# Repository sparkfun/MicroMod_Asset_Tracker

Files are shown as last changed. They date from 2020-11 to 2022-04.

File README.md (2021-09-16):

# MicroMod Asset Tracker Carrier Board

SparkFun MicroMod Asset Tracker Carrier Board (https://www.sparkfun.com/products/17272)

[*SparkFun MicroMod Asset Tracker Carrier Board (DEV-17272)*](https://www.sparkfun.com/products/17272)

The MicroMod Asset Tracker Carrier Board provides you with a toolkit to monitor and track the location of your assets. Built around the u-blox SARA-R510M8S module, the asset tracker offers Secure Cloud LTE-M data communication for multi-regional use and has an integrated u-blox M8 GNSS receiver for accurate positioning information. The SARA-R5 supports many different forms of data communication from full TCP/IP sockets and packet switched data, through HTTP Get/Put/Post, FTP (the SARA has a built-in file system), Ping, to good old SMS text messaging!

The Asset Tracker Carrier Board has an integrated ICM-20948 Inertial Measurement Unit (IMU) for Nine Degree-Of-Freedom orientation and movement detection. Want to send a message if your asset is moved? The Asset Tracker can do that! The board also has a built-in digital microphone and so can send an alert as soon as a noise is detected too.

The SparkFun Asset Tracker Carrier Board also has a built-in micro-SD card socket for data logging. Power options include both USB-C and LiPo battery (with built-in charging and battery fuel gauge), but you can provide power via a breakout pin too.

## Repository Contents

* **/Examples** - A set of examples demonstrating how to use each component on the Asset Tracker. Run these from the Arduino IDE.
* **/Documentation** - Datasheets etc.
* **/Hardware** - Eagle PCB, SCH and LBR design files. Full schematic in PDF format.
* **[LICENSE.md](./LICENSE.md)** - License details

## Documentation

* **[SparkFun u-blox SARA-R5 Arduino Library](https://github.com/sparkfun/SparkFun_u-blox_SARA-R5_Arduino_Library)** - An Arduino library for the SARA-R5 Module
* **[Hookup Guide](https://learn.sparkfun.com/tutorials/micromod-asset-tracker-carrier-board-hookup-guide)** - Basic Hookup Guide for the MicroMod Asset Tracker Carrier Board
* **[Getting Started with MicroMod](https://learn.sparkfun.com/tutorials/getting-started-with-micromod)** -  A tutorial to help you get started with the MicroMod Ecosystem.
* **[Designing with MicroMod](https://learn.sparkfun.com/tutorials/designing-with-micromod)** - A tutorial to walk you through the specs of the MicroMod processor and carrier board as well as the basics of incorporating the MicroMod form factor into your own PCB designs.

## Product Versions

* [DEV-17272](https://www.sparkfun.com/products/17272) - The MicroMod Asset Tracker Carrier Board uses the u-blox SARA-R5 LTE-M / NB-IoT module to provide a powerful development tool.

## License Information

This product is _**open source**_!

Please review the LICENSE.md file for license information.

If you have any questions or concerns on licensing, please contact technical support on our [SparkFun forums](https://forum.sparkfun.com/viewforum.php?f=152).

Distributed as-is; no warranty is given.

- Your friends at SparkFun.

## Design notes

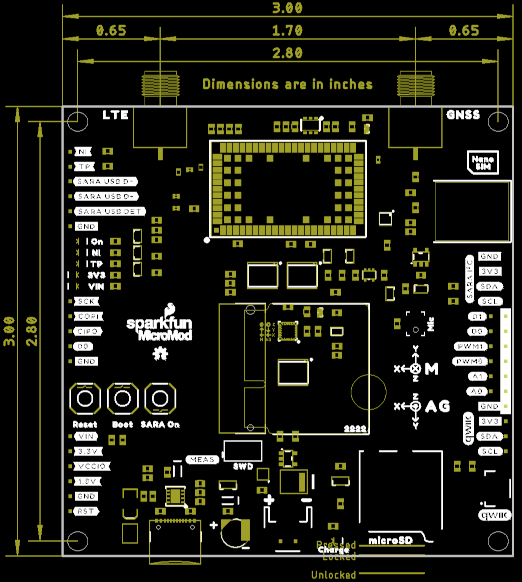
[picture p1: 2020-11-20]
img/Dimensions.png

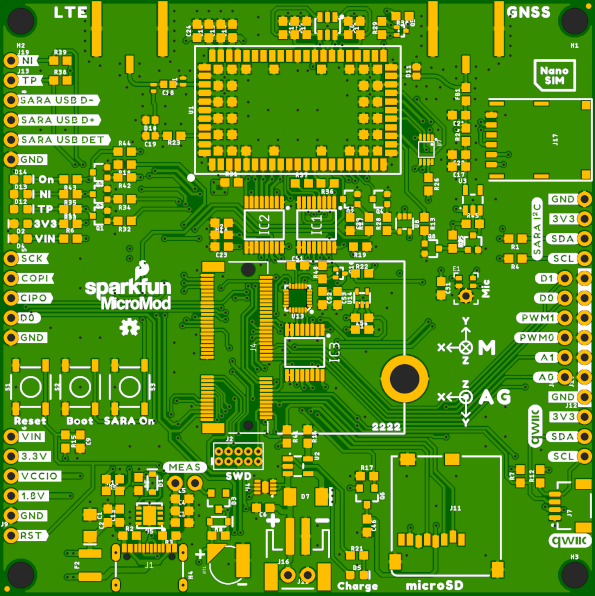
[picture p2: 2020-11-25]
img/Top.png

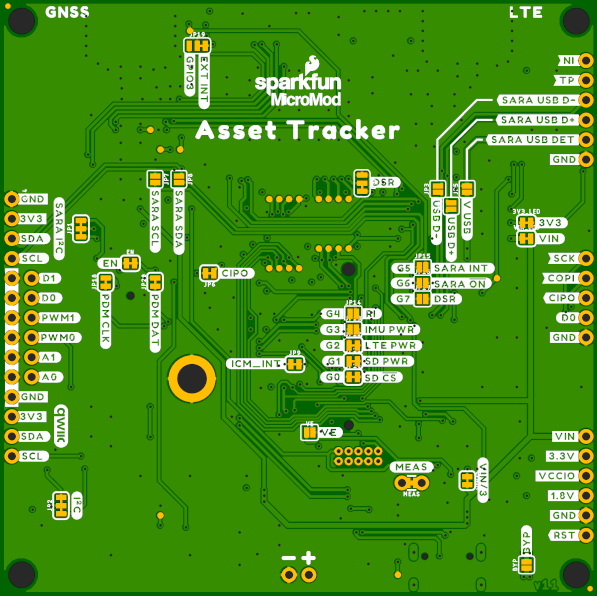
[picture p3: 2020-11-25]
img/Bottom.png

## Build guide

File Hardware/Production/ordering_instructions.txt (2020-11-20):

panel size, 167x194mm
PCB thickness, 1.6mm
number of layers, 4
soldermask color, Red
silkscreen color, White
oz copper, 1oz
finish, HASL lead free
stencils, top
pcs per panel, 4
min trace width, 0.2032mm / 0.0080in
min drill size, 0.3000mm / 0.0118in
filename to layer stackup 1/2/3/4: GTL, GL2, GL3, GBL

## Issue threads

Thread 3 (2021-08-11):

add support for STM32 Micromod

adpjhu, 2021-08-11:
i added the following to "AssetTrackerPins.h"

seems to have made it work w/ STM32 micromod

`#if defined(ARDUINO_ARCH_STM32)
#define G7 -1
#define BATTVIN3 BATT_VIN
#define I2CINT INT
HardwareSerial Serial1(RX1, TX1);
#endif`

PaulZC, 2021-08-12:
Thank you @adpjhu ,
We will test this and add it to the examples as soon as we can.
Best wishes,
Paul

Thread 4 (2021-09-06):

Charger compatibility with Lifepo4

cdumitras-plog, 2021-09-06:
Hello,
Considering the use of this device (car tracker), the use of litium ion batteries might be considered a risk.
In cars depending on conditions temperature can be high, increasing the risk of fire with lithium ion.

Is this charger compatible with lifepo4 ?
If not could you consider a future revision with such a change ?

I consider this device to be a very strong platform for asset tracking,
Thank you for your hard work!

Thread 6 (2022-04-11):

No example nor processor board that works

ajsb85, 2022-04-11:
Hi, I try all the processor boards and all the examples.

And no one works.

Seems the **nRF5280 Processor** is the perfect for this carrier board, but is broken the Arduino file when you install the board.

https://github.com/sparkfun/MicroMod_Processor_Board-nRF52840/issues/3

Cheers.

PaulZC, 2022-04-11:
Hi Alexander (@ajsb85 ),

They do work - trust me - I've been using them today.

For the nRF52840, there are some extra steps to create the SparkFun MicroMod nRF52840 Processor Board. Follow the instructions here:

https://learn.sparkfun.com/tutorials/micromod-nrf52840-processor-hookup-guide/arduino-software-setup

Then select the correct Board:

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

If you are still having problems, please upload a copy of any error messages you are seeing.

Best wishes,
Paul

ajsb85, 2022-04-21:
No.
And I read the forum posts and nothing works.
The board base from Arduino was updated and not the files provided by SparkFun.
If you can tell me which version of the Arduino boards works I can downgrade it...

PaulZC, 2022-04-21:
Hello Alexander,

I followed the instructions in the hook-up guide - but it was a few months ago. I am using "Arduino Mbed OS Boards" Version 1.3.1 DEPRECATED:

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

But I see that the repository has been updated so that it should work with the newer "Arduino Mbed OS Nano Boards" Version 3.0.1:

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

Please try "Arduino Mbed OS Nano Boards" Version 3.0.1 - using the link in the hook-up guide:

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

https://github.com/sparkfun/MicroMod_Processor_Board-nRF52840/archive/master.zip

If you still have problems, please try "Arduino Mbed OS Boards" Version 1.3.1 DEPRECATED - and use the link below to download an older version of the SF_MM_nRF52840_PB files. This is the same one I am using.

https://github.com/sparkfun/MicroMod_Processor_Board-nRF52840/archive/4bddb83c139195fad9654aa633374239504ced05.zip

If, after this, you are still having problems, please provide more information:

Do you see any errors in the Arduino IDE when compiling and uploading the code?

What do you see in the Serial Monitor when the code is running?

How do you have the board connected?

Which LEDs are lit up on the board?

Have you tried the simplest "AssetTracker_Example1_Blink"? Does the LED on the processor board blink?

Thank you,
Paul

ajsb85, 2022-04-26:
Dear @PaulZC .

I tried both versions of the DEPRECATED board 3.0.1 and 1.3.1 and I got the same error for both in the process of the uploading.

```
An error occurred while uploading the sketch
SAM-BA operation failed****
```

ajsb85, 2022-04-27:
It's working. (1.3.1)
I really appreciate it.

PaulZC, 2022-12-30:
Closing... Please re-open if you need more help with this.
Best,
Paul

Closed 2022-12-30.

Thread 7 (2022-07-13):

AWS IoT ExpressLink Asset Tracker |  Cannot initialize SARA with Examples on ESP32

alex-dsbz, 2022-07-13:
Hi.

I'm having issues with running any examples that include the initialisation of the SARA board. All of the other examples work with no issue.

Let's take Example12 - Identification.
When uploading it to the MicroMod ESP32, this is what I get from the serial monitor of Arduino

````
Asset Tracker Example

Initializing the SARA-R5...
...this may take ~25 seconds if the SARA is off.
...it may take ~5 seconds if it just turned on.

Press any key to continue...
init: Begin module init.
sendCommandWithResponse: Command: E0
init: Module failed echo test.
init: Begin module init.
init: Attempting autobaud connection to module.
sendCommandWithResponse: Command: +IPR=9600
sendCommandWithResponse: Command:
sendCommandWithResponse: Command: +IPR=9600
sendCommandWithResponse: Command:
sendCommandWithResponse: Command: +IPR=9600
sendCommandWithResponse: Command:
sendCommandWithResponse: Command: +IPR=9600
sendCommandWithResponse: Command:
sendCommandWithResponse: Command: +IPR=9600
sendCommandWithResponse: Command:
sendCommandWithResponse: Command: +IPR=9600
sendCommandWithResponse: Command:
init: Begin module init.
init: Power cycling module.
powerOff: complete
powerOn: complete

````
This sequence loops a couple time before its asking to manually turn on the SARA.

However the SARA IS turned on, and is being turned on and off by the initialisation script.

I've posted on the Sparkfun forum, but did not get any assistance so far.

I would love to be pointed in the right direction as I've exhausted all I could think off...

PaulZC, 2022-07-13:
Hi @alex-dsbz ,

From the title of the issue, I guess you are using the ESP32 MicroMod Processor Board?
Which version of the Espressif ESP32 board package do you have installed? (Probably v2.0.3 or 2.0.4?)
Which LEDs are illuminated?
Have you made any changes to the jumper links on the board?

Many thanks,
Paul

alex-dsbz, 2022-07-13:
Hi Paul,

Thanks for reaching back, I really appreciate it!

So I'm using the AWS IoT ExpressLink SARA-R5 Starter Kit  https://www.sparkfun.com/products/18450

All I have done is swap the Asset Tracker Update Tool MicroMod with the ESP32 and plug the carrier board by USB-C to my macbook.

I have uploaded the following example https://github.com/sparkfun/MicroMod_Asset_Tracker/tree/main/Examples/AssetTracker_Example12_Identification

In terms of Boards package, I have two installed:
- esp32 by Espressif Systems version 1.0.6 (that's the latest according to the Arduino IDE)
- Sparkfun Esp32 Boards version 1.0.1

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

In terms of LED:
- VIN is orange
- 3C3 is red
- On is white

I hope that answers your questions :)

Alex

PaulZC, 2022-07-13:
Hi Alex (@alex-dsbz ),

Many thanks for the detailed reply.

The SARA-R5 on the AWS IoT ExpressLink version of the Asset Tracker was programmed with special firmware. From the product page:

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

I must confess, I've never had one of those boards to test.

I designed the original version of the board and wrote the original Arduino Library and Examples. But I did all of that with boards running the standard SARA-R5 firmware - which responds to 'regular' AT commands.

I suspect the AWS version of the module is ignoring or not responding to the initial **E0** 'ping'. But, I've got no way to confirm that just now...

I'm really not sure how best to proceed.

I can ask my colleagues to send over one of the AWS boards so I can replicate your set-up. But, the end result _could_ be that it's just not possible to use the Arduino examples with that board...

Apologies,
Paul

alex-dsbz, 2022-07-13:
Oh I see, that does make sense!
At least now I know, there is nothing wrong with the board :)

Thanks a lot for your help!

PaulZC, 2022-07-23:
Hi Alex,

Just adding a link to the forum issue, just in case anyone else has the same issue:

https://forum.sparkfun.com/viewtopic.php?p=234780#p234780

Very best wishes,
Paul

Closed 2022-07-13.

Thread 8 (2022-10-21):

MicroMod Asset Tracker Carrier board with Samd51, Arduino IDE giving Missing FBQN error

jwalway, 2022-10-21:
Hello,

I have a **SparkFun MicroMod Asset Tracker Carrier** board that has a **Samd51 processor** board plugged into it.
I'm using the **Arduino IDE 2.0** in an attempt to code the board. I'm on _Windows 10_ and the board is plugged into my usb com port. Right now I'm just experimenting. I'm relatively new to this kind of programming. I downloaded libraries for both boards. When I attempt to compile a short sketch/script I get the following error: **Missing FBQN** (Fully Qualified Board Name). I can't get the Arduino IDE to recognize the Asset Tracker board, nor do I see it listed among their boards. I also don't see the samd51. I do see samd21.

I'm trying the first example here:
[https://learn.sparkfun.com/tutorials/mi ... o-examples](https://learn.sparkfun.com/tutorials/micromod-asset-tracker-carrier-board-hookup-guide/arduino-examples)

Can anyone help me with this?

Thanks!
...John

jwalway, 2022-10-21:
>

Thanks PaulZC

I'm following that guide, but am running into an issue here:
[Samd51 Hook up guide](https://learn.sparkfun.com/tutorials/micromod-samd51-processor-board-hookup-guide/setting-up-the-arduino-ide)

Where it says:
_First, you'll need to install a variety of tools, including [low-level ARM Cortex libraries](http://www.arm.com/products/processors/cortex-m/cortex-microcontroller-software-interface-standard.php) full of generic code, [arm-gcc](https://launchpad.net/gcc-arm-embedded) to compile your code, and [bossa](http://www.shumatech.com/web/products/bossa) to upload over the bootloader. These tools come packaged along with Arduino's SAMD board definitions for the Arduino Zero._

For the arm-gcc they link to I don't see exactly what to download.  I'm here on Windows 10.   Put another way, I'm not sure what to download.

PaulZC, 2022-10-22:
Hi John,

Let's see if we can get you going. I know there are some issues in IDE 2.0 that will be important here and which will be corrected in the next release. But let's see if standard 2.0 works...

Steps:

* Install IDE 2.0
* Open File \ Preferences
* Click on the icon to the right of "Additional board manager URLs"
* Copy and paste in the following:

```
https://raw.githubusercontent.com/sparkfun/Arduino_Boards/main/IDE_Board_Manager/package_sparkfun_index.json
```

* Click OK
* Open Tool \ Board \ Boards Manager  or click the icon second from top at the left of the screen ("Boards Manager")
* In the search box type "SAMD"
* Install Arduino SAMD Boards (32-bits ARM Cortex-M0+) **Version 1.8.13**
* Scroll down the list, install SparkFun SAMD Boards Version 1.8.7
* Click on the icon on the left of the screen to close the board manager
* Click on the books icon below it to open the Library Manager  or open Tools \ Manage Libraries
* In the search box type "sparkfun sara" - that's sparkfun space sara
  * You can't use underscores at the moment. That will be fixed in the next release
* Install the SparkFun u-blox SARA-R5 Arduino Library Version 1.1.3
* In the search box, replace sara with gnss
* Scroll down and install the SparkFun u-blox GNSS Arduino Library Version 2.2.17
* Go to this page:
  * https://github.com/sparkfun/MicroMod_Asset_Tracker
* Click on the green Code icon
* Select Download Zip
* Go to your downloads folder and unzip the MicroMod_Asset_Tracker-main.zip
* Go into the Zip file Examples folder
* Rick-click and Copy the AssetTracker_Example1_Blink folder
* Go to your Documents \ Arduino folder and paste it there
* In the IDE, click the books Library Manager icon on the left to close the Library Manager
* Click on the folder icon above it and open your "Sketchbook"
* Highlight the AssetTracker_Example1_Blink
* Click on the three dots to the right
* Select "Open Sketch In New Window"
* The example code will pop up in a new window
* Click on the AssetTracker_Example1_Blink.ino tab to see the main example code
* Install the SAMD51 processor and connect the Asset Tracker via USB as per the hook-up guide
* Click on the Select Board drop-down list at the top left of the window, below Help
* Select the SparkFun SAMD51 MicroMod
* Click on the -> Upload icon at the top left of the window, below Edit
* The code should compile and upload
* The blue LED on the processor board should start to flash

Your screen should look like this when you're done:

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

If you need to select the board and port manually, use:

* Tools \ Board \ SparkFun SAMD Boards \ SparkFun SAMD51 MicroMod
* Tools \ Port
  * Select the COM port which has SparkFun SAMD51 MicroMod named next to it

You shouldn't need to install any additional USB drivers - fingers crossed!

That will hopefully get you started! If you see any issues, please report back here. Please cut and paste in screenshots to help.

Best wishes,
Paul

jwalway, 2022-10-22:
Thanks Paul!

That was very thorough!

I had previously done every step you mentioned, except that I didn't have the _SparkFun u-blox GNSS Arduino Library_ installed.   So I installed that.

**There were a couple of other differences:**
1) I can't find the _SparkFun SAMD Boards version1.8.7_... previously I had installed the _1.8.3 version_.

2) I had installed the following url in preferences:

https://raw.githubusercontent.com/sparkfun/Arduino_Boards/master/IDE_Board_Manager/package_sparkfun_index.json

Yours is slightly different.  So, I added yours as well (the master vs main in url string)

https://raw.githubusercontent.com/sparkfun/Arduino_Boards/main/IDE_Board_Manager/package_sparkfun_index.json

**Everything went smoothly until I came to the final step, which is where my main trouble was.**

I can't see the board to select for the COM port.    I see samd21 versions, but **no samd51**.

I've uploaded a screenshot...

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

Perhaps this is the one problem I have.

PaulZC, 2022-10-22:
Hi John (@jwalway ),

Please delete the “master” entry from the additional URLs. Close and re-open the IDE. Open the Library Manager. Search for SAMD. Do you see an option to update the SparkFun SAMD boards to 1.8.7?

The issue - I think - is that the IDE is using the old ‘master’ link preferentially. That hasn’t been updated in some time and probably doesn’t include the SAMD51 PB.

Best,
Paul

jwalway, 2022-10-22:
Thanks a million, Paul!   That fixed it.  It's doing the one second led on/off cycle!    It's a beautiful thing. :-)

Regards,
...John

PaulZC, 2022-10-22:
Happy days!

The GNSS library was probably a red herring. I just had a vague memory that some of the later examples needed it. The SARA-R5 has a GNSS built-in, but you can’t access it directly. You need to do it through the SARA’s AT command interface.

Anyway… I’m going to close this, but will take an action to update any existing master references in our guides. GitHub and we both updated the branch name to main some time ago.

Please open a fresh issue if you find any more gremlins…

Best wishes,
Paul

Closed 2022-10-22.

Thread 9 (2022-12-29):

Serial monitor doesn't seem to work on my STM32 setup

SelimOzel, 2022-12-29:
Hi There. I got the Micromod Asset tracker and the Sparkfun STM32 processor board. I can run the blink example and upload the code. I already did the software and hardware setup for setting up SARA library and board definitions.

However, I can't seem to get anything out on the serial monitor. I'm wondering if the default serial initialization in the examples has a mismatch or not.

I can provide more details if it'll help.

Best,
Selim

PaulZC, 2022-12-29:
Hi Selim (@SelimOzel ),

There is something strange going on... Possibly to do with auto-bauding? Let me explain:

I started by opening Asset Tracker Example12 (Identification) in the Arduino IDE 1.8.19. I tried to upload the code to the Asset Tracker and STM32 MicroMod processor. After remembering to hold the Boot button while pressing and releasing the Reset button, I got the code to upload OK. Like you, I could not see any serial traffic in the Serial Monitor.

I inserted a ```delay(2000);``` at the start of ```setup()```. That allowed me to see the initial "Asset Tracker Example" messages. When I pressed a key to continue, I eventually got a "Unable to communicate with the SARA" message.

I uncommented the ```assetTracker.enableDebugging(SERIAL_PORT);``` to see the debug messages. I reset the board and pressed a key again. I could see the library code attempting to communicate with the SARA, but it was not receiving any replies. Eventually it timed out.

I removed the STM32 MM processor and inserted the Firmware Update Tool instead. I installed [m-center](https://www.u-blox.com/en/product/m-center). I opened the CH340 COM port at **9600 Baud** (no handshaking) and was able connect to the SARA and see its serial number etc..

I then re-installed the STM32 processor and re-ran the example code. This time it worked:

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

So, I'm not sure what is going on... I suspect the SARA had accidentally been set to a different Baud rate and that opening m-center somehow reset it?

Please check you have:
* U(S)ART support set to "Enabled (no generic 'Serial')"
* USB support set to "CDC (generic 'Serial' supercede U(S)ART"

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

There is more useful information in the [STM32 MM PB Hook-Up Guide](https://learn.sparkfun.com/tutorials/micromod-stm32-processor-hookup-guide#software-setup-and-programming) - but I guess you've already seen that.

I hope this helps. Please let me know if this lets you communicate with the SARA.

Best wishes,
Paul

SelimOzel, 2022-12-30:
Hey Paul,

Thank for taking the time to look into this! I think your suggestion worked. I'll give more details though, maybe it can help others.

I felt something was off with my unit when I went through the Hook-up Guide for the first time. Examples with serial monitor only worked if I added a delay, just like you did, to the beginning of the loop. I also had to remove the code from setup and add it under loop with a "run once" flag. So, I ended up adding a pseudo-setup routine in my code. This seemed to work and I could go through examples 12-13 with my custom code.

At some point this setup broke down. I stopped seeing any serial output on my monitor. Just this morning, I followed what you did. I removed STM32 board and attached the update board, I opened a port and set it to 9600 Baud on m-center. Then, I removed update board and reinstalled STM32 board. After I uploaded the custom code, I could see serial output this time!

Apparently uBlox was set to a wrong Baud rate internally and this was breaking the serial communication that I use to debug over USB as well.

Best,
Selim

PaulZC, 2022-12-30:
Thanks for the update Selim - I'm glad that's working for you,

I don't understand what's going on. The STM32 is a little bit tricky - with its USART and CDC configuration. Maybe some rogue traffic is output on the TX1/RX1 pins during the DFU upload - which causes the SARA to auto-baud to the wrong speed? It's just a guess though... (Once the SARA has chosen an auto-baud speed, you can only change it by: resetting the chip, or by sending the correct AT commands at auto-baud speed.)

I'm going to close this, but I will pin it so others can find it.

Thanks again for the diagnostics,
Paul

Closed 2022-12-30.

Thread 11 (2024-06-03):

Reducing power consumption of Micromod Asset Tracker

jeronimoagullo, 2024-06-03:
Hi!

I would like to know the lowest current consumption of the Micromod Asset Tracker board (without the CPU consumption).

I have removed the CPU board and I have measured around 16mA feeding the board with 3.3V and with the modem off. I noticed that the IMU was enabled, but putting "ICM20948_EN" pin of its voltage regulator to GND, the current consumption reduces a couple to milliamps to 13-14mA.

I am wondering which peripherals are consuming these 13-14mA and how could I eliminate this remaining power consumption by configuring the CPU pins properly. The idea es to reduce the power consumption during sleep state (I am using the nrf52840 board which consumes less than 1mA in idle state)

PaulZC, 2024-06-04:
Hi Jerónimo (@jeronimoagullo ),

The Asset Tracker wasn't really designed with low current in mind. You will need to work through the schematic, tracing where those mA are going.

Some suggestions:

* Powering the board from 3.3V may not be the best choice for measuring current draw. You may be leaking current back through the 3.3V regulator. What is the draw if you provide power from VIN or V_BATT?
* Are all the LEDs off? Have you disabled the VIN and 3.3V LEDs by opening the jumper links?
* Do you have an active GNSS antenna connected? The regulator U3 _should_ be off when the SARA is powered off, but do check. Check Q8 and Q9 too.
* What state is the Qwiic I2C bus in? Are you leaking current through the 2.2K I2C pull-ups? Likewise for the level-shifted SARA I2C bus.
* Do you have an SD card inserted? The SD card will be powered on by default. Pull MICROSD_PWR high (3.3V) to disable it.
* Check SPI_SDI. Are you drawing current through the R22 2.2K pull-up? Likewise for SARA_INT and R30.
* Is USB connected?

I'm going to close this, but please feel free to ask here for more help if you need it.

Best wishes,
Paul

jeronimoagullo, 2024-06-04:
Hi @PaulZC

thank you very much for your response. I checked out some of your recommendations but no all of them. Just as a comment, after openning this issue I was checking the level shifters (TI SN74AVC4T774) and it seems that when the inputs are floating, there is a large current leakage, so I suppose it is the main reason. FYI: https://e2e.ti.com/support/logic-group/logic/f/logic-forum/945807/sn74avc4t774-sn74avc4t774rsvr-consuming-high-current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

In any case, the board is awesome, great job :D

Best regards,
Jerónimo

Closed 2024-06-04.

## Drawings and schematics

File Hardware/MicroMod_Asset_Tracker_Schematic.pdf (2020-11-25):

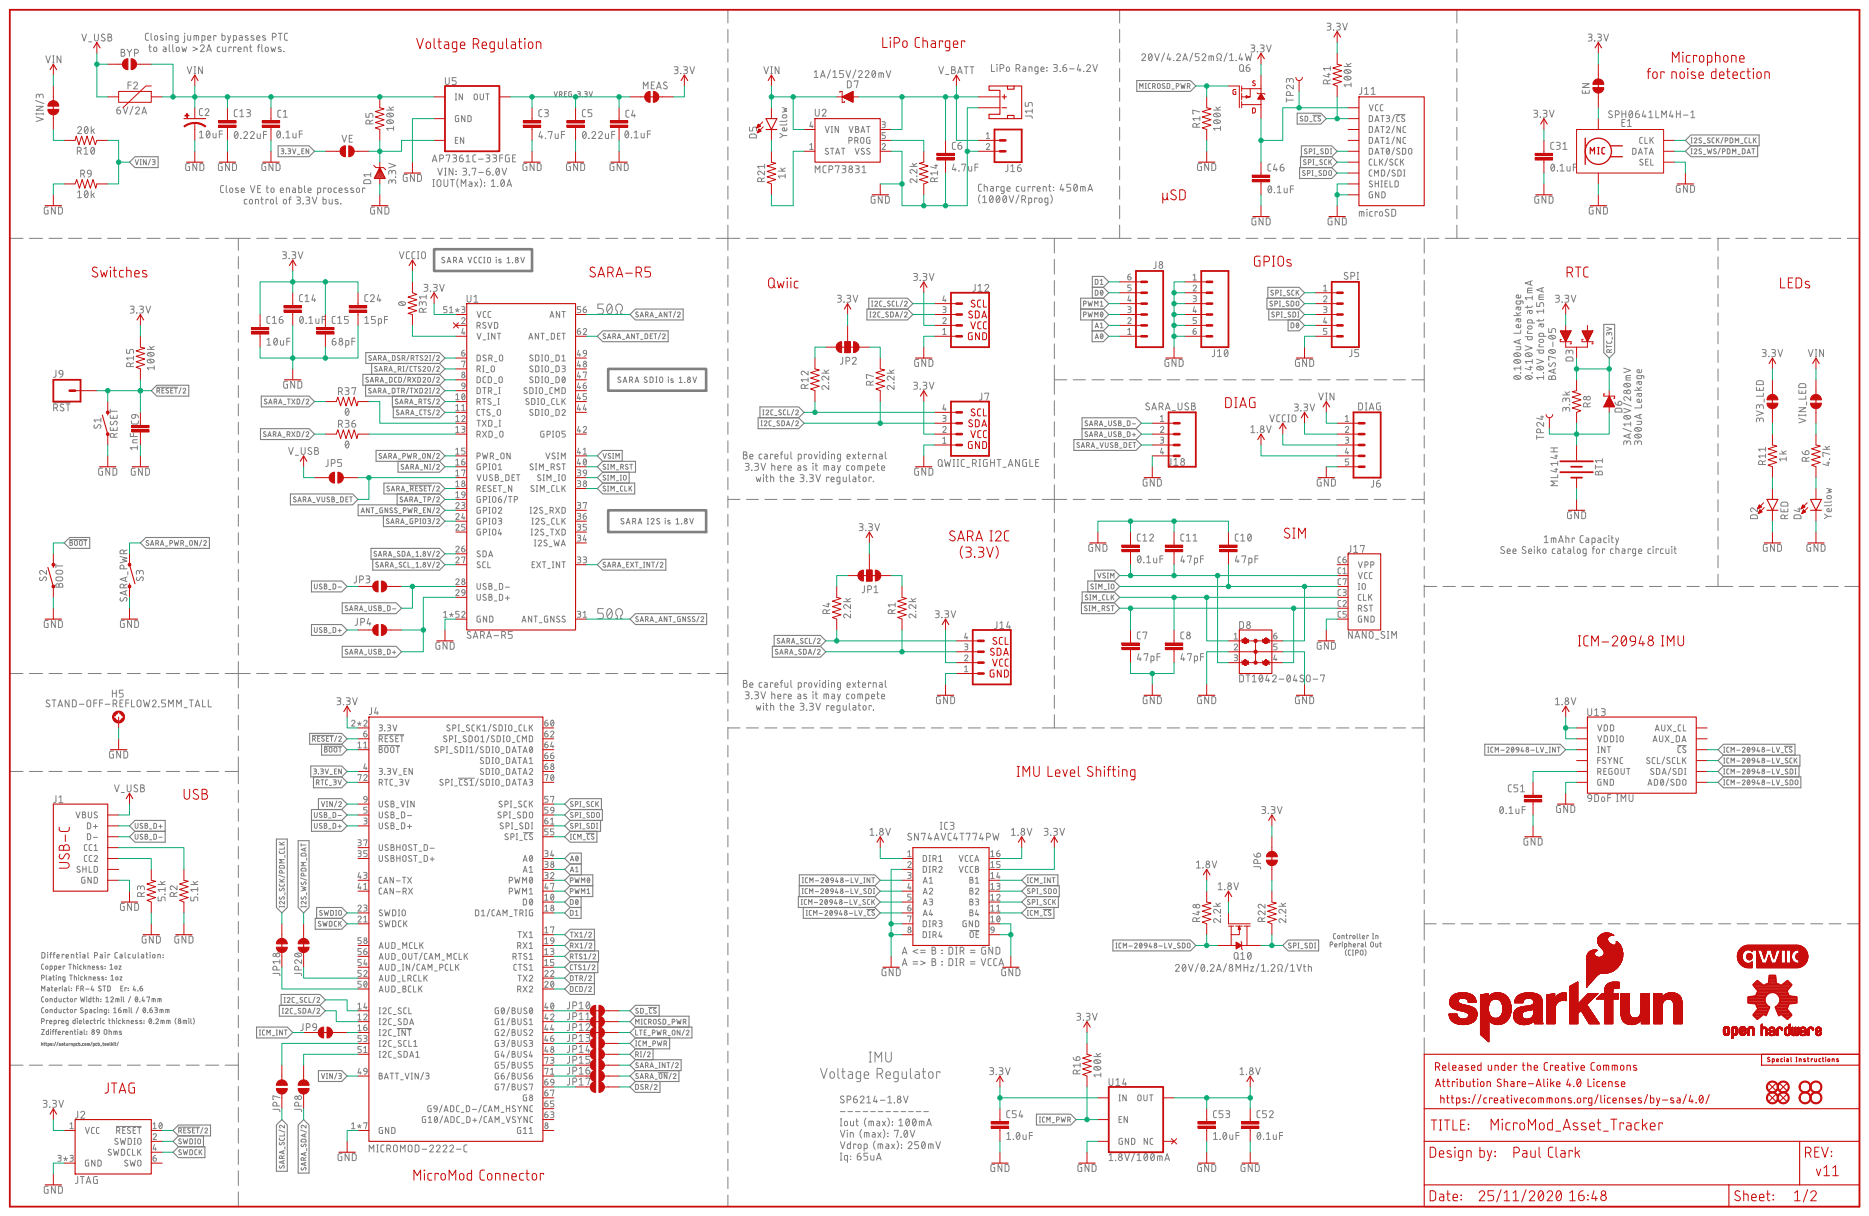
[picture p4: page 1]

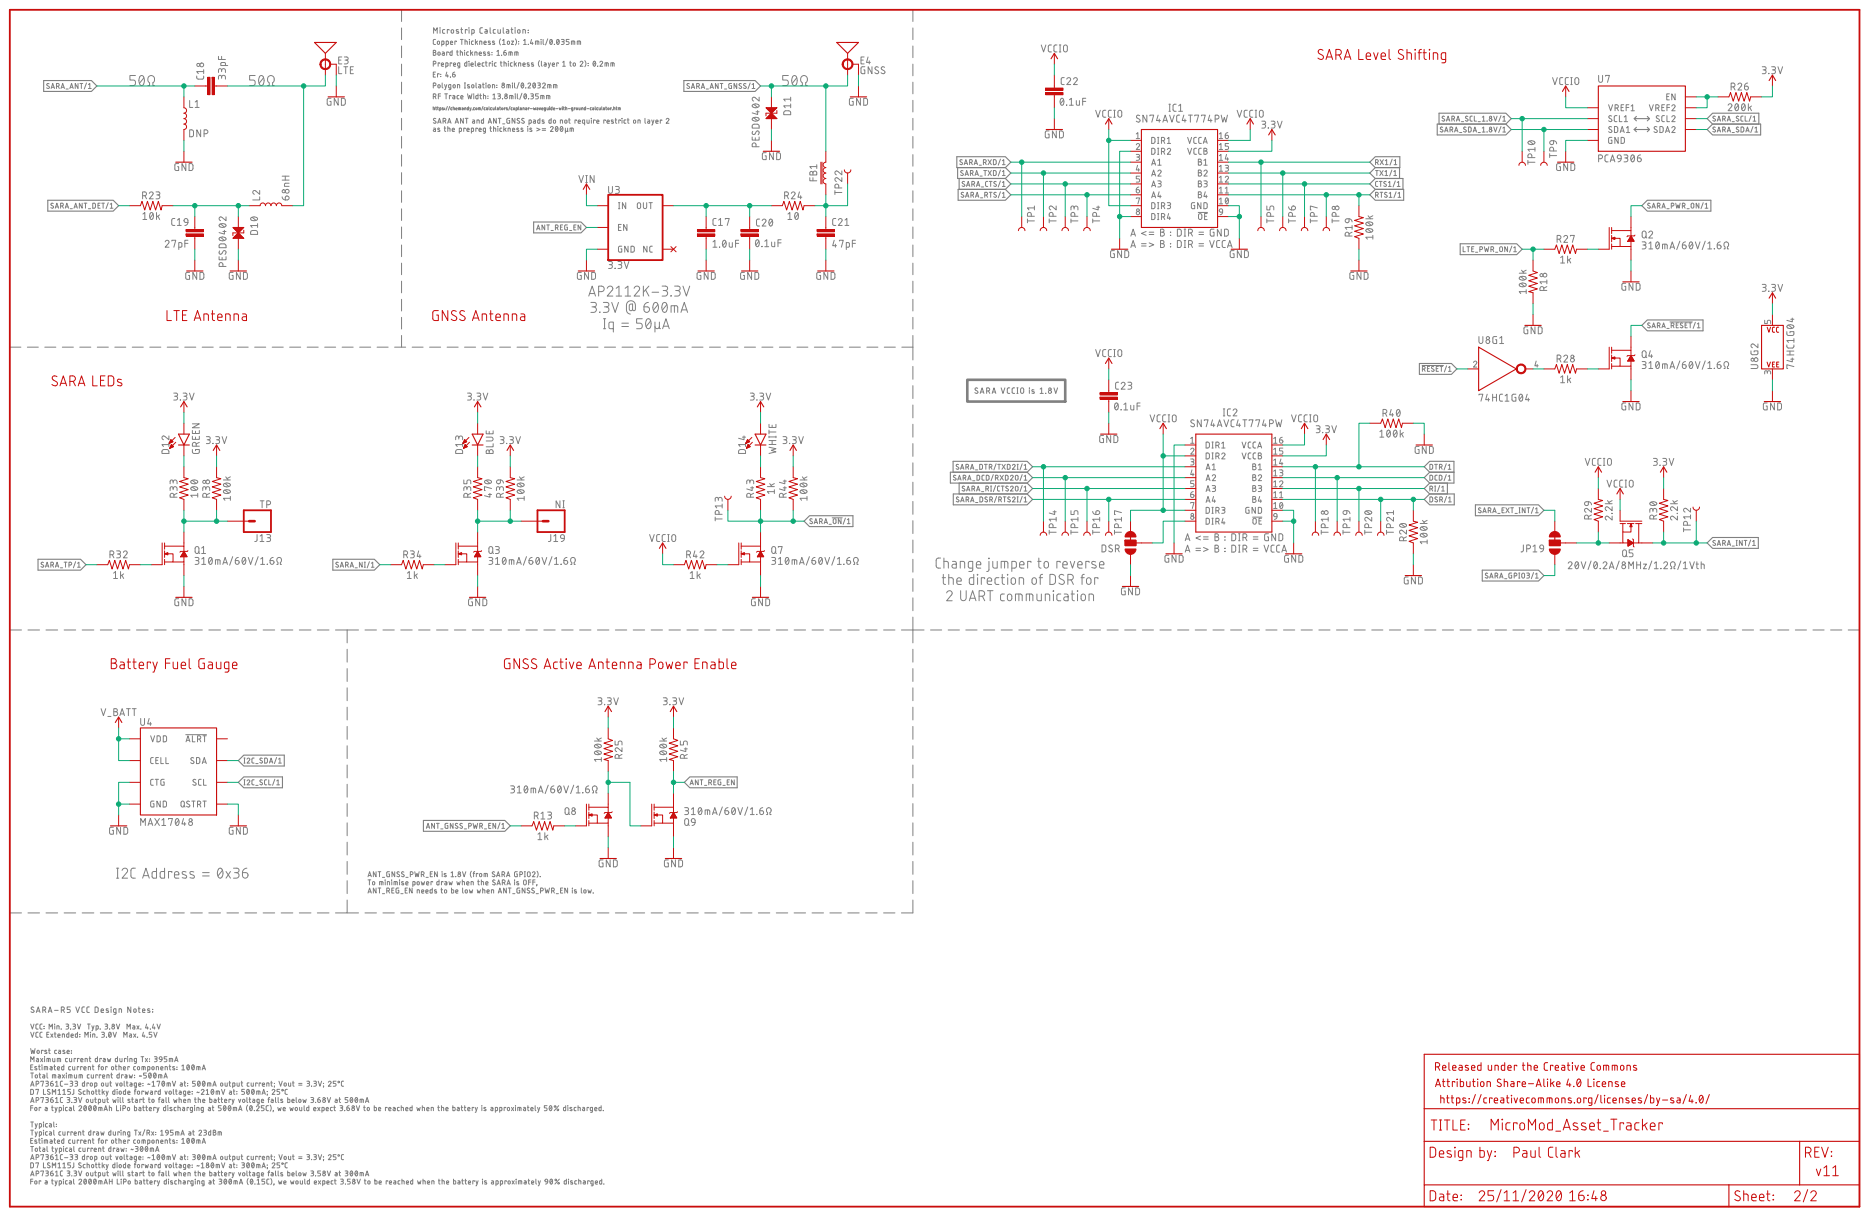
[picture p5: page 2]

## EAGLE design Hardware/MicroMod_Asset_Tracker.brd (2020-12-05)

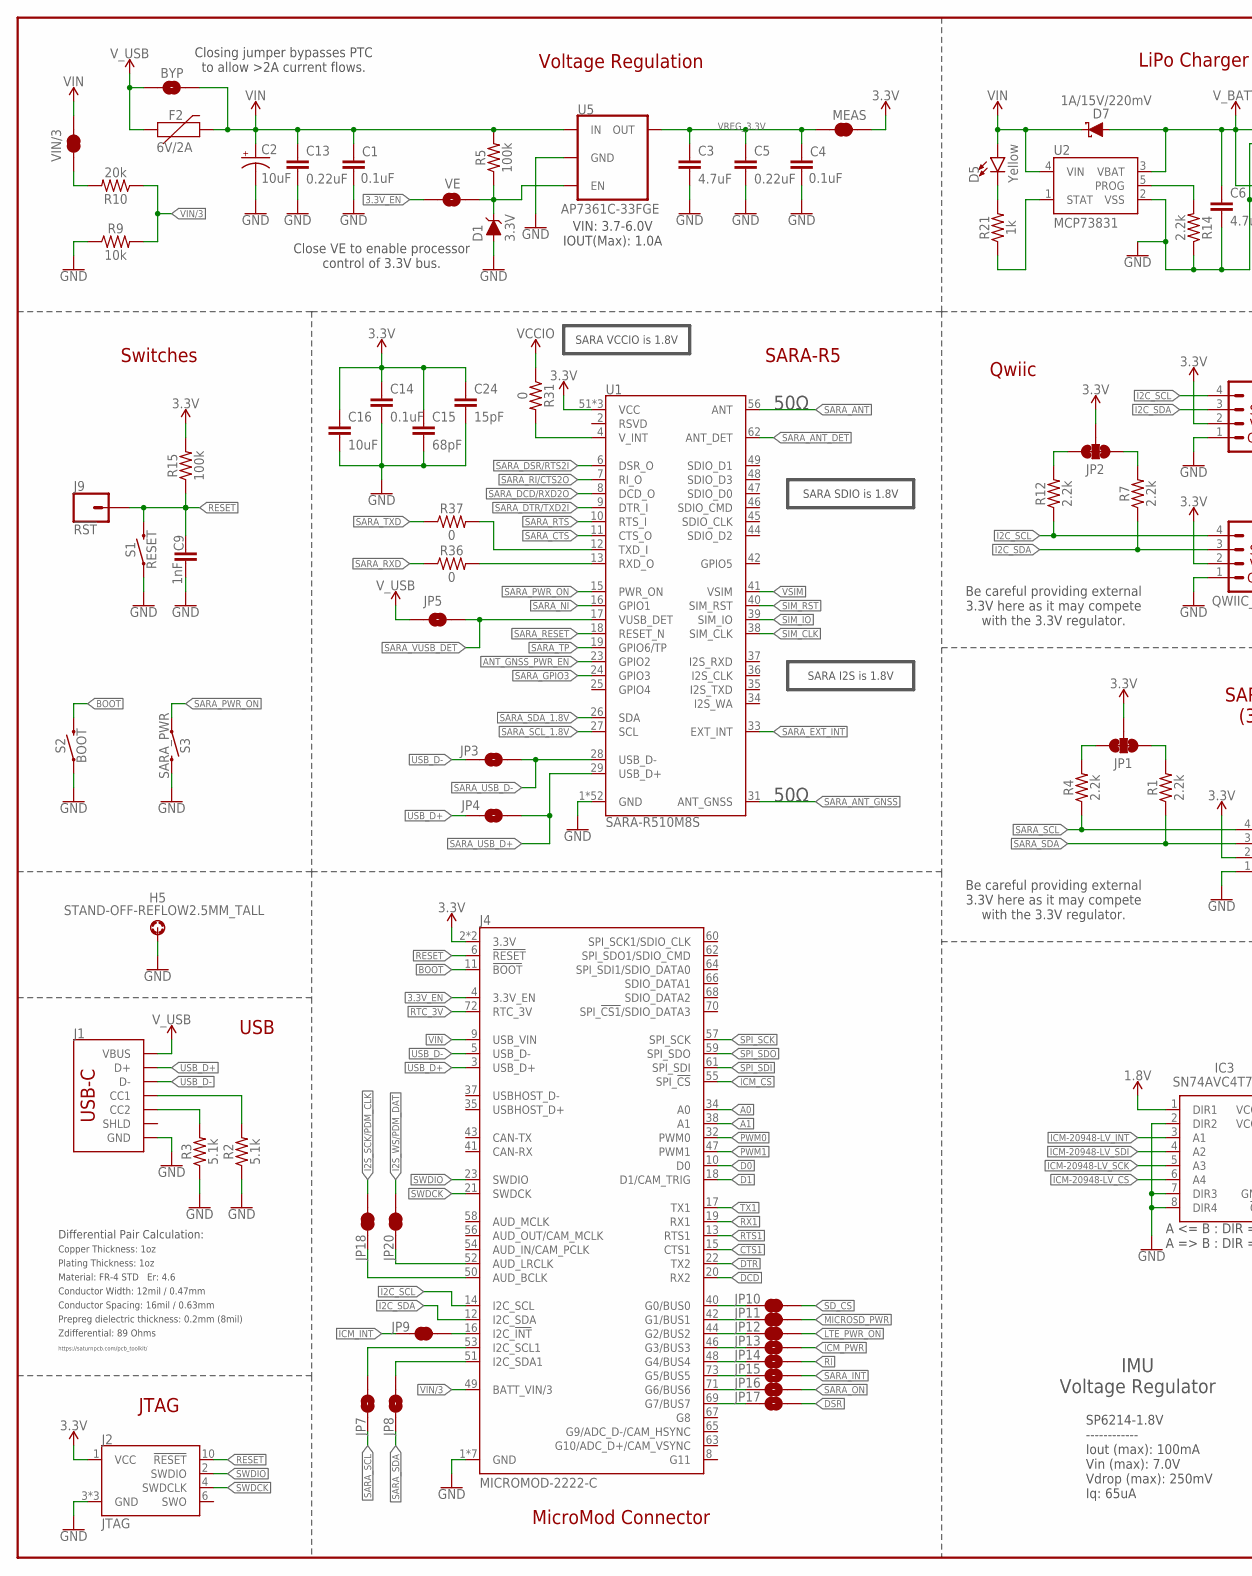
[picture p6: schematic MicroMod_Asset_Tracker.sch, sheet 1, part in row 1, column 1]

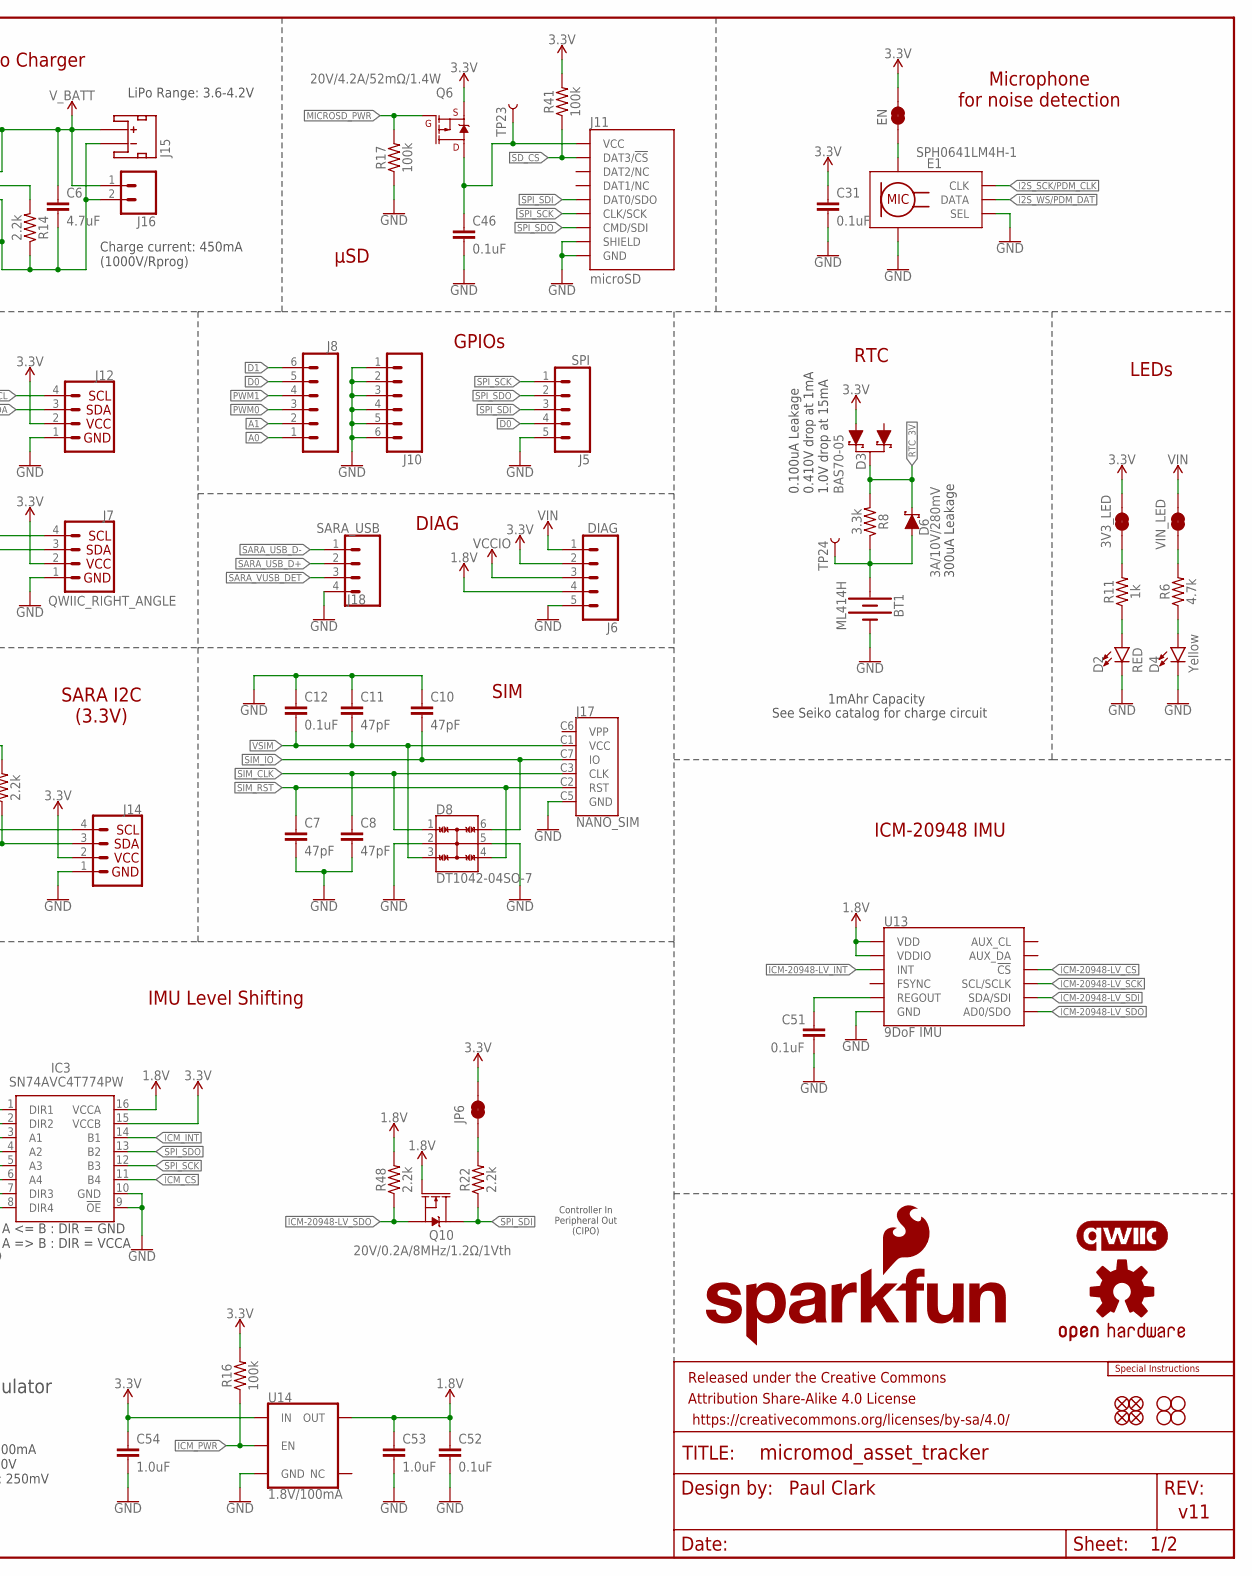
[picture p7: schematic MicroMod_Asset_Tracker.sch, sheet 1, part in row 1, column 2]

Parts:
3V3_LED: JUMPER-SMT_2_NC_TRACE_SILK; SMT-JUMPER_2_NC_TRACE_SILK
BT1: ML414H; ML414H_IV01E
BYP: JUMPER-SMT_2_NO_SILK; SMT-JUMPER_2_NO_SILK
C1, C4, C12, C14, C31, C46, C51, C52: 0.1uF; 0603
C2: 10uF; EIA3216
C3, C6: 4.7uF; 0603
C5, C13: 0.22uF; 0603
C7, C8, C10, C11: 47pF; 0603
C9: 1nF; 0603
C15: 68pF; 0603
C16: 10uF; 0603
C24: 15pF; 0603
C53, C54: 1.0uF; 0603
D1: 3.3V; SOD-323
D2: RED; LED-0603
D3: BAS70-05; SOT23-3
D4, D5: Yellow; LED-0603
D6: 3A/10V/280mV; SOD-323
D7: 1A/15V/220mV; DO-214BA
D8: DT1042-04SO-7; SOT23-6L
E1: SPH0641LM4H-1; SPH0641LM4H-1_MICROPHONE
EN: JUMPER-SMT_2_NC_TRACE_SILK; SMT-JUMPER_2_NC_TRACE_SILK
F2: 6V/2A; 1210
FD1, FD2, FD3, FD4: FIDUCIALUFIDUCIAL; FIDUCIAL-MICRO
FRAME1: FRAME-LEDGER; CREATIVE_COMMONS
H1, H2, H3, H4: STAND-OFF
H5: STAND-OFF-REFLOW2.5MM_TALL; STAND-OFF-REFLOW-M2.5
IC3: SN74AVC4T774PW; SOP65P640X120-16N
J1: USB_C_4-LAYER_PADS; USB-C-16P_4LAYER-PADS
J2: JTAG; 2X5-PTH-1.27MM
J4: MICROMOD-2222-C; M.2-CONNECTOR-E
J5: SPI; 1X05_NO_SILK
J6: DIAG; 1X05_NO_SILK
J7: QWIIC_RIGHT_ANGLE; JST04_1MM_RA
J8, J10: CONN_06NO_SILK_NO_POP; 1X06_NO_SILK
J9: !RST!; 1X01_NO_SILK
J11: microSD; MICRO-SD-SOCKET
J12, J14: I2C_STANDARD_NO_SILK; 1X04_NO_SILK
J15: JST_2MM_MALE; JST-2-SMD
J16: CONN_021X02_NO_SILK; 1X02_NO_SILK
J17: NANO_SIM; NANO_SIM_WURTH_693043020611
J18: SARA_USB; 1X04_NO_SILK
JP1, JP2: JUMPER-SMT_3_2-NC_TRACE_SILK; SMT-JUMPER_3_2-NC_TRACE_SILK
JP3, JP4, JP5, JP7, JP8, JP13, JP14, JP15, JP16, JP17: JUMPER-SMT_2_NO_SILK; SMT-JUMPER_2_NO_SILK
JP6, JP9, JP10, JP11, JP12, JP18, JP20: JUMPER-SMT_2_NC_TRACE_SILK; SMT-JUMPER_2_NC_TRACE_SILK
LOGO1: SFE_LOGO_NAME_FLAME.1_INCH; SFE_LOGO_NAME_FLAME_.1
LOGO2: QWIIC_LOGO_CONNECTOR; QWIIC_5.5MM
LOGO3: OSHW-LOGOMINI; OSHW-LOGO-MINI
LOGO5: SPECIAL_INSTRUCTIONS-ORDERING; ORDERING_INSTRUCTIONS
MEAS: JUMPER-COMBO_2_NC_TRACE; COMBO-JUMPER_2_NC_TRACE
Q6: 20V/4.2A/52mΩ/1.4W; SOT23-3
Q10: 20V/0.2A/8MHz/1.2Ω/1Vth; SOT-416FL
R1, R4, R7, R12, R14, R22, R48: 2.2k; 0603
R2, R3: 5.1k; 0603
R5, R15, R16, R17, R41: 100k; 0603
R6: 4.7k; 0603
R8: 3.3k; 0603
R9: 10k; 0603
R10: 20k; 0603
R11, R21: 1k; 0603
R31, R36, R37: 0; 0603
S1: RESET; TACTILE_SWITCH_SMD_5.2MM
S2: BOOT; TACTILE_SWITCH_SMD_5.2MM
S3: SARA_PWR; TACTILE_SWITCH_SMD_5.2MM
TP23, TP24: TEST-POINT3; PAD.03X.03
U1: SARA-R510M8S; SARA-LGA
U2: MCP73831; SOT23-5
U5: AP7361C-33FGE; UDFN-8
U13: 9DoF IMU; QFN24-3X3-ICM-20948
U14: 1.8V/100mA; SC70
VE: JUMPER-SMT_2_NO_SILK; SMT-JUMPER_2_NO_SILK
VIN/3: JUMPER-SMT_2_NC_TRACE_SILK; SMT-JUMPER_2_NC_TRACE_SILK
VIN_LED: JUMPER-SMT_2_NC_TRACE_SILK; SMT-JUMPER_2_NC_TRACE_SILK

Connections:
1.8V: C52.1, C53.1, IC3.1 (DIR1), IC3.16 (VCCA), J6.4, Q10.1 (G), R48.2, U13.8 (VDDIO), U13.13 (VDD), U14.5 (OUT)
3.3V: 3V3_LED.2, C14.1, C15.1, C16.1, C24.1, C31.1, C54.1, D3.2 (A1), EN.2, IC3.15 (VCCB), J2.1 (VCC), J4.2 (3.3V), J4.74 (3.3V), J6.2, J7.2, J12.2, J14.2, JP1.2, JP2.2, JP6.2, MEAS.2, MEAS.4 (2), Q6.2 (S), R15.2, R16.2, R41.2, U1.51 (VCC), U1.52 (VCC), U1.53 (VCC), U14.1 (IN); also elsewhere on the board
3.3V_EN: J4.4 (3.3V_EN), VE.1
!BOOT!: J4.11 (!BOOT!), S2.3 (2), S2.4 (2)
!RESET!: C9.1, J2.10 (!RESET), J4.6 (!RESET!), J9.1, R15.1, S1.3 (2), S1.4 (2); also elsewhere on the board
A0: J4.34 (A0), J8.1
A1: J4.38 (A1), J8.2
ANT_GNSS_PWR_EN: U1.23 (GPIO2); also elsewhere on the board
CHG_LED: R21.1, U2.1 (STAT)
CTS1: J4.15 (CTS1); also elsewhere on the board
D0: J4.10 (D0), J5.4, J8.5
D1: J4.18 (D1/CAM_TRIG), J8.6
DCD: J4.20 (RX2); also elsewhere on the board
DSR: JP17.2; also elsewhere on the board
DTR: J4.22 (TX2); also elsewhere on the board
G0: J4.40 (G0/BUS0), JP10.1
G1: J4.42 (G1/BUS1), JP11.1
G2: J4.44 (G2/BUS2), JP12.1
G3: J4.46 (G3/BUS3), JP13.1
G4: J4.48 (G4/BUS4), JP14.1
G5: J4.73 (G5/BUS5), JP15.1
G6: J4.71 (G6/BUS6), JP16.1
G7: J4.69 (G7/BUS7), JP17.1
GND: BT1.-, C1.2, C2.-, C3.2, C4.2, C5.2, C6.2, C7.2, C8.2, C9.2, C10.1, C11.1, C12.1, C13.2, C14.2, C15.2, C16.2, C24.2, C31.2, C46.2, C51.2, C52.2, C53.2, C54.2, D1.A, D2.C, D4.C, D8.2, D8.5, E1.2 (SEL), E1.3 (GND), E1.6 (GND), E1.7 (GND), E1.8 (GND), H5.1, IC3.2 (DIR2), IC3.7 (DIR3), IC3.8 (DIR4), IC3.9 (!OE), IC3.10 (GND), J1.GND, J1.GND2 (GND), J2.3 (GND), J2.5 (GND), J2.9 (GND), J4.1 (GND), J4.7 (GND), J4.33 (GND), J4.36 (GND), J4.39 (GND), J4.45 (GND), J4.75 (GND), J5.5, J6.5, J7.1, J10.1, J10.2, J10.3, J10.4, J10.5, J10.6, J11.CD1 (SHIELD), J11.GND, J11.GND1 (GND), J11.GND3 (GND), J12.1, J14.1, J15.1 (-), J16.2, J17.C5 (GND), J18.4, R2.1, R3.1, R9.1, R14.1, R17.1, S1.1, S1.2 (1), S2.1, S2.2 (1), S3.3 (2), S3.4 (2), U1.1 (GND), U1.3 (GND), U1.5 (GND), U1.14 (GND), U1.20 (GND), U1.21 (GND), U1.22 (GND), U1.30 (GND), U1.32 (GND), U1.43 (GND), U1.50 (GND), U1.54 (GND), U1.55 (GND), U1.57 (GND), U1.58 (GND), U1.59 (GND), U1.60 (GND), U1.61 (GND), U1.63 (GND), U1.64 (GND), U1.65 (GND), U1.66 (GND), U1.67 (GND), U1.68 (GND), U1.69 (GND), U1.70 (GND), U1.71 (GND), U1.72 (GND), U1.73 (GND), U1.74 (GND), U1.75 (GND), U1.76 (GND), U1.77 (GND), U1.78 (GND), U1.79 (GND), U1.80 (GND), U1.81 (GND), U1.82 (GND), U1.83 (GND), U1.84 (GND), U1.85 (GND), U1.86 (GND), U1.87 (GND), U1.88 (GND), U1.89 (GND), U1.90 (GND), U1.91 (GND), U1.92 (GND), U1.93 (GND), U1.94 (GND), U1.95 (GND), U1.96 (GND), U2.2 (VSS), U5.4 (GND), U5.EP (GND), U13.18 (GND), U13.20 (GND), U14.2 (GND); also elsewhere on the board
I2C_SCL: J4.14 (I2C_SCL), J7.4, J12.4, R12.1; also elsewhere on the board
I2C_SDA: J4.12 (I2C_SDA), J7.3, J12.3, R7.1; also elsewhere on the board
I2S_SCK/PDM_CLK: E1.4 (CLK), JP18.2
I2S_WS/PDM_DAT: E1.1 (DATA), JP20.2
ICM-20948-LV_!CS!: IC3.6 (A4), U13.22 (!CS)
ICM-20948-LV_INT: IC3.3 (A1), U13.12 (INT)
ICM-20948-LV_SCK: IC3.5 (A3), U13.23 (SCL/SCLK)
ICM-20948-LV_SDI: IC3.4 (A2), U13.24 (SDA/SDI)
ICM-20948-LV_SDO: Q10.2 (S), R48.1, U13.9 (AD0/SDO)
ICM_!CS!: IC3.11 (B4), J4.55 (SPI_!CS!)
ICM_INT: IC3.14 (B1), JP9.1
ICM_PWR: JP13.2, R16.1, U14.3 (EN)
LTE_PWR_ON: JP12.2; also elsewhere on the board
MICROSD_PWR: JP11.2, Q6.1 (G), R17.2
unnamed: R6.2, VIN_LED.1
unnamed: JP1.3, R4.2
unnamed: JP1.1, R1.2
unnamed: E1.5 (VDD), EN.1
unnamed: J4.53 (I2C_SCL1), JP7.2
unnamed: 3V3_LED.1, R11.2
unnamed: D2.A, R11.1
unnamed: D4.A, R6.1
unnamed: JP2.3, R12.2
unnamed: J1.A5 (CC1), R2.2
unnamed: J1.B5 (CC2), R3.2
unnamed: D1.C, R5.1, U5.5 (EN), VE.2
unnamed: JP2.1, R7.2
unnamed: BT1.+, D6.A, R8.1, TP24.P$1
unnamed: J4.51 (I2C_SDA1), JP8.2
unnamed: R10.2, VIN/3.1
unnamed: J4.16 (I2C_!INT!), JP9.2
unnamed: R14.2, U2.5 (PROG)
unnamed: D5.C, R21.2
unnamed: JP6.1, R22.2
unnamed: C51.1, U13.10 (REGOUT)
unnamed: R31.2, U1.4 (V_INT)
unnamed: R36.2, U1.13 (RXD_O)
unnamed: R37.2, U1.12 (TXD_I)
unnamed: J4.52 (AUD_LRCLK), JP20.1
unnamed: J4.50 (AUD_BCLK), JP18.1
PWM0: J4.32 (PWM0), J8.3
PWM1: J4.47 (PWM1), J8.4
RI: JP14.2; also elsewhere on the board
RTC_3V: D3.3 (C), D6.C, J4.72 (RTC_3V), R8.2
RTS1: J4.13 (RTS1); also elsewhere on the board
RX1: J4.19 (RX1); also elsewhere on the board
SARA_!ON!: JP16.2; also elsewhere on the board
SARA_!RESET!: U1.18 (RESET_N); also elsewhere on the board
SARA_ANT: U1.56 (ANT); also elsewhere on the board
SARA_ANT_DET: U1.62 (ANT_DET); also elsewhere on the board
SARA_ANT_GNSS: U1.31 (ANT_GNSS); also elsewhere on the board
SARA_CTS: U1.11 (CTS_O); also elsewhere on the board
SARA_DCD/RXD2O: U1.8 (DCD_O); also elsewhere on the board
SARA_DSR/RTS2I: U1.6 (DSR_O); also elsewhere on the board
SARA_DTR/TXD2I: U1.9 (DTR_I); also elsewhere on the board
SARA_EXT_INT: U1.33 (EXT_INT); also elsewhere on the board
SARA_GPIO3: U1.24 (GPIO3); also elsewhere on the board
SARA_INT: JP15.2; also elsewhere on the board
SARA_NI: U1.16 (GPIO1); also elsewhere on the board
SARA_PWR_ON: S3.1, S3.2 (1), U1.15 (PWR_ON); also elsewhere on the board
SARA_RI/CTS2O: U1.7 (RI_O); also elsewhere on the board
SARA_RTS: U1.10 (RTS_I); also elsewhere on the board
SARA_RXD: R36.1; also elsewhere on the board
SARA_SCL: J14.4, JP7.1, R4.1; also elsewhere on the board
SARA_SCL_1.8V: U1.27 (SCL); also elsewhere on the board
SARA_SDA: J14.3, JP8.1, R1.1; also elsewhere on the board
SARA_SDA_1.8V: U1.26 (SDA); also elsewhere on the board
SARA_TP: U1.19 (GPIO6/TP); also elsewhere on the board
SARA_TXD: R37.1; also elsewhere on the board
SARA_USB_D+: J18.2, JP4.2, U1.29 (USB_D+)
SARA_USB_D-: J18.1, JP3.2, U1.28 (USB_D-)
SARA_VUSB_DET: J18.3, JP5.2, U1.17 (VUSB_DET)
SD_!CS!: J11.CS/DAT3 (DAT3/!CS!), JP10.2, R41.1
SD_PWR: C46.1, J11.VCC, Q6.3 (D), TP23.P$1
SIM_CLK: C8.1, D8.1, J17.C3 (CLK), U1.38 (SIM_CLK)
SIM_IO: C10.2, D8.6, J17.C7 (IO), U1.39 (SIM_IO)
SIM_RST: C7.1, D8.4, J17.C2 (RST), U1.40 (SIM_RST)
SPI_SCK: IC3.12 (B3), J4.57 (SPI_SCK), J5.1, J11.SCLK (CLK/SCK)
SPI_SDI: J4.61 (SPI_SDI), J5.3, J11.DO/DAT0 (DAT0/SDO), Q10.3 (D), R22.1
SPI_SDO: IC3.13 (B2), J4.59 (SPI_SDO), J5.2, J11.DI/CMD (CMD/SDI)
SWDCK: J2.4 (SWDCLK), J4.21 (SWDCK)
SWDIO: J2.2 (SWDIO), J4.23 (SWDIO)
TX1: J4.17 (TX1); also elsewhere on the board
USB_D+: J1.A6 (D+), J1.B6 (D+), J4.3 (USB_D+), JP4.1
USB_D-: J1.A7 (D-), J1.B7 (D-), J4.5 (USB_D-), JP3.1
VCCIO: J6.3, R31.1; also elsewhere on the board
VIN: BYP.2, C1.1, C2.+, C13.1, D5.A, D7.C, F2.2, J4.9 (USB_VIN), J6.1, R5.2, U2.4 (VIN), U5.8 (IN), VIN/3.2, VIN_LED.2; also elsewhere on the board
VIN/3: J4.49 (BATT_VIN/3), R9.2, R10.1
VREG_3.3V: C3.1, C4.1, C5.1, MEAS.1, MEAS.3 (1), U5.1 (OUT)
VSIM: C11.2, C12.2, D8.3, J17.C1 (VCC), U1.41 (VSIM)
V_BATT: C6.1, D7.A, J15.2 (+), J16.1, U2.3 (VBAT); also elsewhere on the board
V_USB: BYP.1, F2.1, J1.VBUS1 (VBUS), J1.VBUS2 (VBUS), JP5.1

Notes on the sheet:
μSD
300uA Leakage
See Seiko catalog for charge circuit
1mAhr Capacity
Closing jumper bypasses PTC to allow >2A current flows.
JTAG
USB
GPIOs
Microphone for noise detection
RTC
Voltage Regulation
MicroMod Connector
0.100uA Leakage 0.410V drop at 1mA 1.0V drop at 15mA
Paul Clark
v11
VIN: 3.7-6.0V IOUT(Max): 1.0A
Be careful providing external 3.3V here as it may compete with the 3.3V regulator.
Close VE to enable processor control of 3.3V bus.
Qwiic
LEDs
Switches
SARA-R5
ICM-20948 IMU
IMU Voltage Regulator
IMU Level Shifting
SP6214-1.8V ------------ Iout (max): 100mA Vin (max): 7.0V Vdrop (max): 250mV Iq: 65uA
Controller In Peripheral Out (CIPO)
LiPo Charger
LiPo Range: 3.6-4.2V
Charge current: 450mA (1000V/Rprog)
SIM
SARA SDIO is 1.8V
50Ω
SARA I2S is 1.8V
DIAG
SARA I2C (3.3V)
SARA VCCIO is 1.8V
Plating Thickness: 1oz
Material: FR-4 STD Er: 4.6
Copper Thickness: 1oz

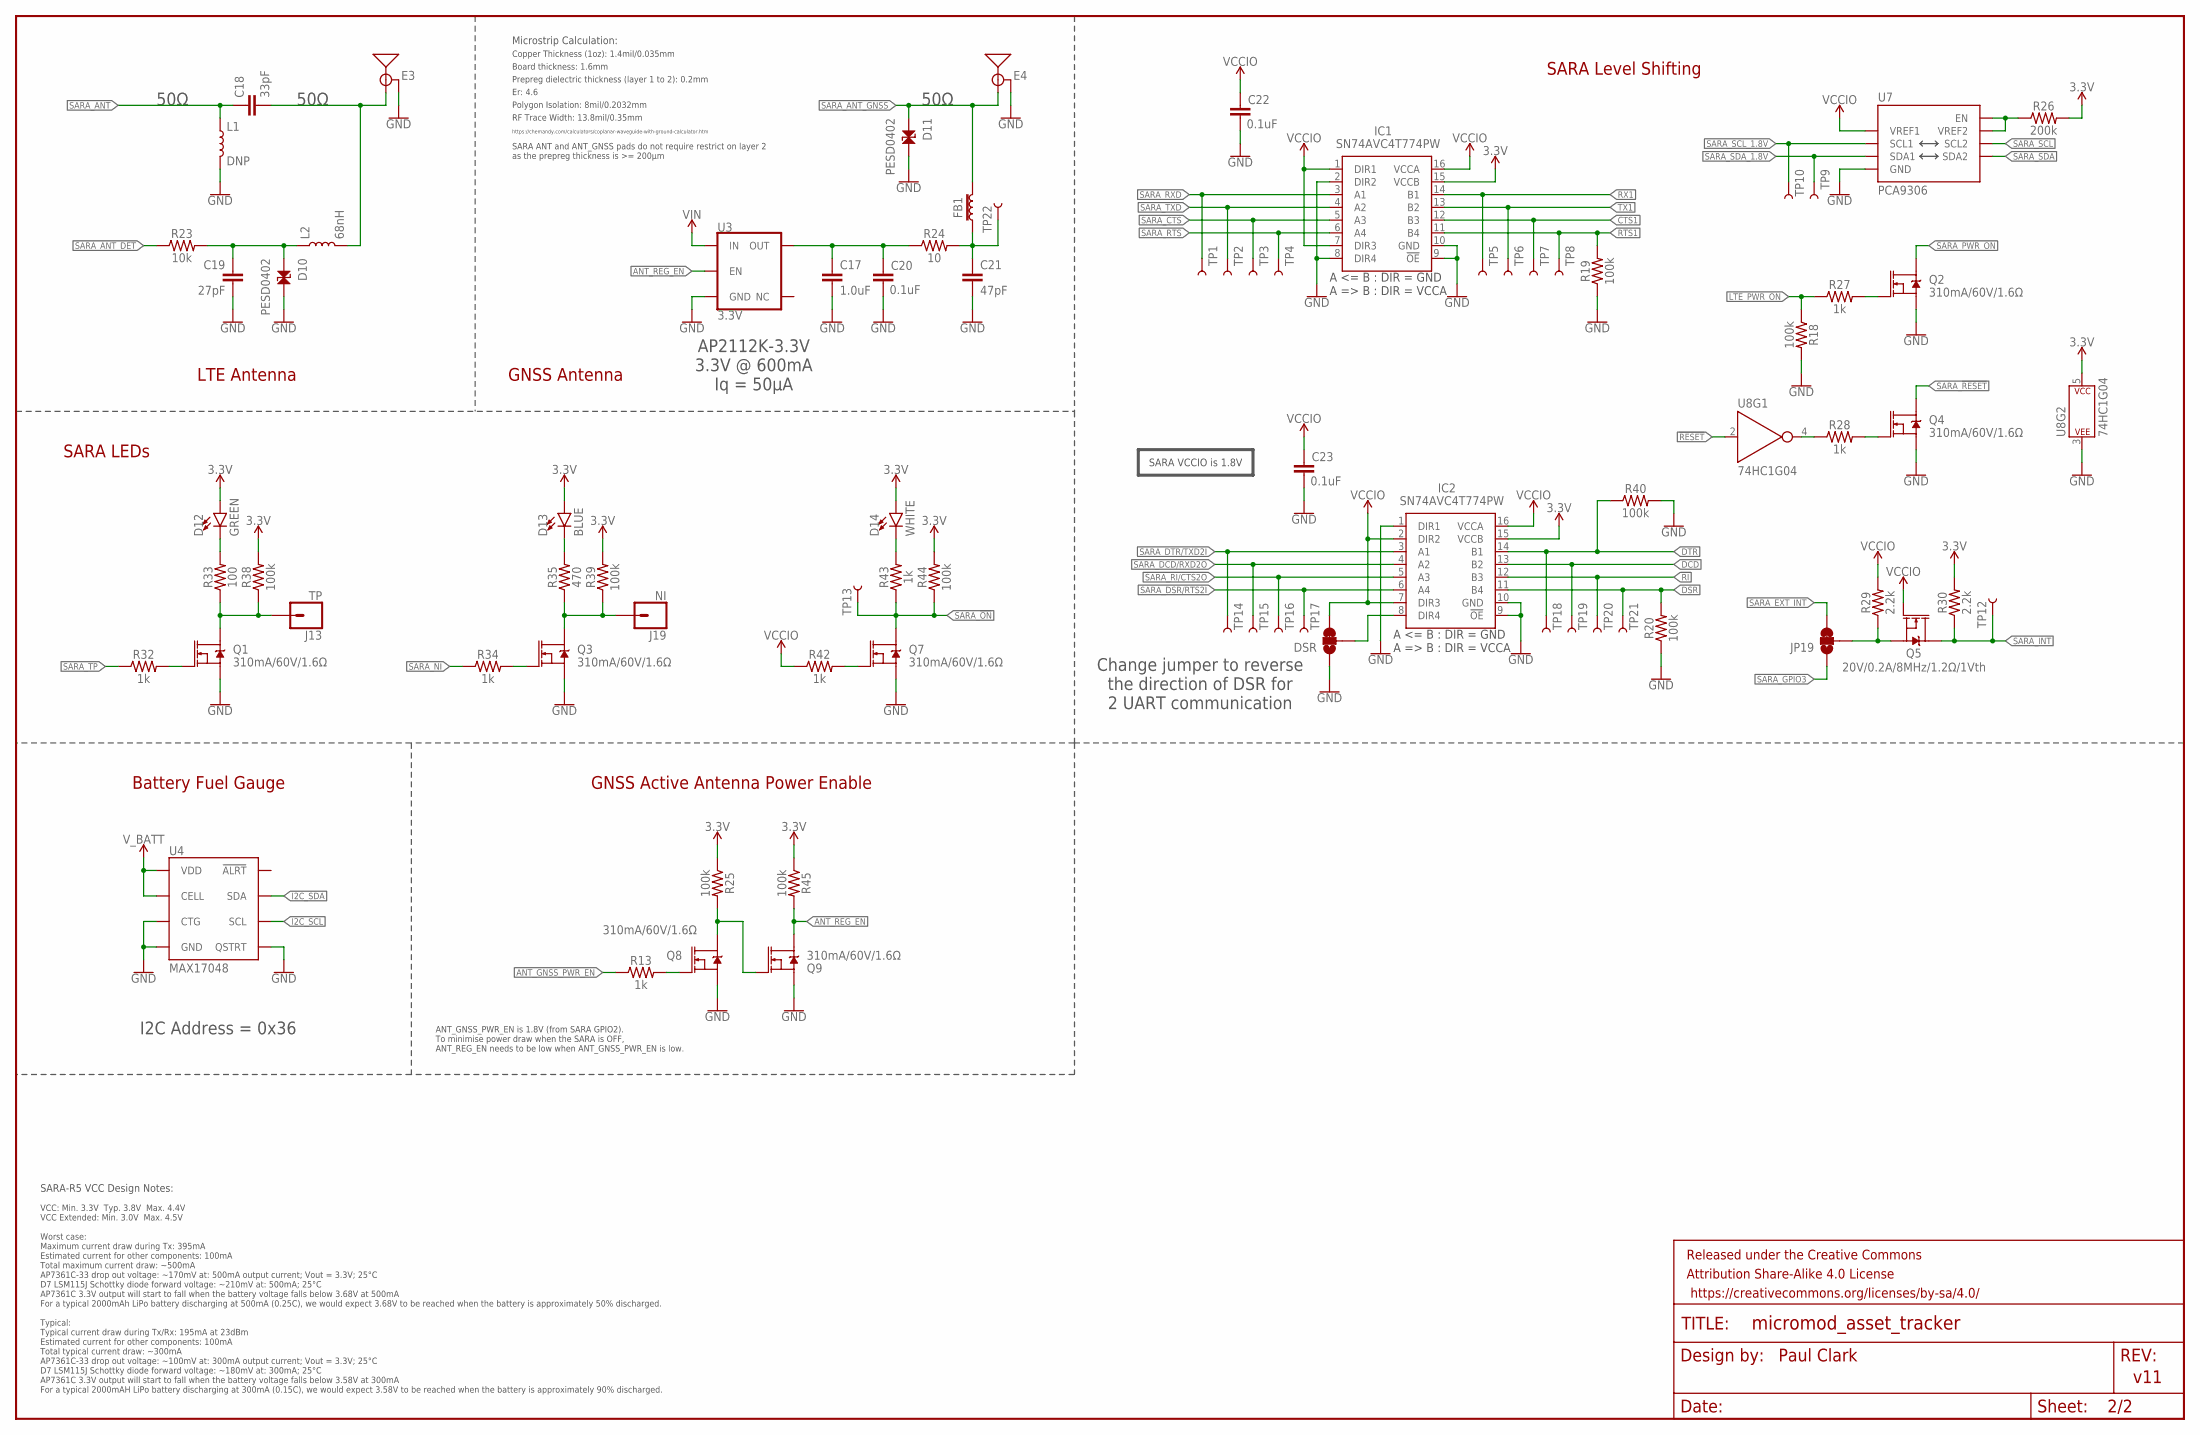
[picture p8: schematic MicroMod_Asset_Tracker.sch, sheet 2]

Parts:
C17: 1.0uF; 0603
C18: 33pF; 0402
C19: 27pF; 0402
C20, C22, C23: 0.1uF; 0603
C21: 47pF; 0603
D10, D11: PESD0402; 0402
D12: GREEN; LED-0603
D13: BLUE; LED-0603
D14: WHITE; LED-0603
DSR: JUMPER-SMT_3_1-NC_TRACE_SILK; SMT-JUMPER_3_1-NC_TRACE_SILK
E3, E4: ANTENNA-SMA-GROUNDEDEDGE_SMA_SMD; SMA-EDGE-SMD
FB1: 30Ω/1.8A; 0603
FRAME2: FRAME-LEDGER; CREATIVE_COMMONS
IC1, IC2: SN74AVC4T774PW; SOP65P640X120-16N
J13: TP; 1X01_NO_SILK
J19: NI; 1X01_NO_SILK
JP19: JUMPER-SMT_3_1-NC_TRACE_SILK; SMT-JUMPER_3_1-NC_TRACE_SILK
L1: DNP; 0402_COILCRAFT
L2: 68nH; 0402_COILCRAFT
Q1, Q2, Q3, Q4, Q7, Q8, Q9: 310mA/60V/1.6Ω; SOT323
Q5: 20V/0.2A/8MHz/1.2Ω/1Vth; SOT-416FL
R13, R27, R28, R32, R34, R42, R43: 1k; 0603
R18, R19, R20, R25, R38, R39, R40, R44, R45: 100k; 0603
R23: 10k; 0603
R24: 10; 0603
R26: 200k; 0603
R29, R30: 2.2k; 0603
R33: 100; 0603
R35: 470; 0603
TP1, TP2, TP3, TP4, TP5, TP6, TP7, TP8, TP9, TP10, TP12, TP13, TP14, TP15, TP16, TP17, TP18, TP19, TP20, TP21, TP22: TEST-POINT3; PAD.03X.03
U3: 3.3V; SOT23-5
U4: MAX17048; DFN-8
U7: PCA9306; VSSOP_8PIN
U8: 74HC1G04; SOT353

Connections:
3.3V: D12.A, D13.A, D14.A, IC1.15 (VCCB), IC2.15 (VCCB), R25.1, R26.2, R30.2, R38.2, R39.2, R44.2, R45.1, U8.5 (P$V+); also elsewhere on the board
!RESET!: U8.2 (A); also elsewhere on the board
ANT_GNSS_PWR_EN: R13.1; also elsewhere on the board
ANT_REG_EN: Q9.3 (D), R45.2, U3.3 (EN)
CTS1: IC1.12 (B3), TP7.P$1; also elsewhere on the board
DCD: IC2.13 (B2), TP19.P$1; also elsewhere on the board
DSR: IC2.11 (B4), R20.2, TP21.P$1; also elsewhere on the board
DTR: IC2.14 (B1), R40.1, TP18.P$1; also elsewhere on the board
GND: C17.2, C19.2, C20.2, C21.2, C22.2, C23.2, D10.2, D11.2, DSR.1, E3.GND@0 (GND), E3.GND@1 (GND), E4.GND@0 (GND), E4.GND@1 (GND), IC1.2 (DIR2), IC1.8 (DIR4), IC1.9 (!OE), IC1.10 (GND), IC2.1 (DIR1), IC2.9 (!OE), IC2.10 (GND), L1.P$2 (2), Q1.2 (S), Q2.2 (S), Q3.2 (S), Q4.2 (S), Q7.2 (S), Q8.2 (S), Q9.2 (S), R18.2, R19.1, R20.1, R40.2, U3.2 (GND), U4.1 (CTG), U4.4 (GND), U4.6 (QSTRT), U4.9 (GND), U7.P1 (GND), U8.3 (P$V-); also elsewhere on the board
I2C_SCL: U4.7 (SCL); also elsewhere on the board
I2C_SDA: U4.8 (SDA); also elsewhere on the board
LTE_PWR_ON: R18.1, R27.1; also elsewhere on the board
unnamed: C18.2, E3.SIG (SIGNAL), L2.P$2 (2)
unnamed: C19.1, D10.1, L2.P$1 (1), R23.2
unnamed: R26.1, U7.P7 (VREF2), U7.P8 (EN)
unnamed: DSR.2, IC2.8 (DIR4)
unnamed: C17.1, C20.1, R24.1, U3.5 (OUT)
unnamed: C21.1, FB1.1, R24.2, TP22.P$1
unnamed: Q2.1 (G), R27.2
unnamed: Q4.1 (G), R28.2
unnamed: R28.1, U8.4 (Y)
unnamed: Q1.1 (G), R32.2
unnamed: J13.1, Q1.3 (D), R33.1, R38.1
unnamed: D12.C, R33.2
unnamed: Q3.1 (G), R34.2
unnamed: J19.1, Q3.3 (D), R35.1, R39.1
unnamed: D13.C, R35.2
unnamed: Q8.1 (G), R13.2
unnamed: Q8.3 (D), Q9.1 (G), R25.2
unnamed: JP19.2, Q5.2 (S), R29.1
unnamed: Q7.1 (G), R42.2
unnamed: D14.C, R43.2
RI: IC2.12 (B3), TP20.P$1; also elsewhere on the board
RTS1: IC1.11 (B4), R19.2, TP8.P$1; also elsewhere on the board
RX1: IC1.14 (B1), TP5.P$1; also elsewhere on the board
SARA_!ON!: Q7.3 (D), R43.1, R44.1, TP13.P$1; also elsewhere on the board
SARA_!RESET!: Q4.3 (D); also elsewhere on the board
SARA_ANT: C18.1, L1.P$1 (1); also elsewhere on the board
SARA_ANT_DET: R23.1; also elsewhere on the board
SARA_ANT_GNSS: D11.1, E4.SIG (SIGNAL), FB1.2; also elsewhere on the board
SARA_CTS: IC1.5 (A3), TP3.P$1; also elsewhere on the board
SARA_DCD/RXD2O: IC2.4 (A2), TP15.P$1; also elsewhere on the board
SARA_DSR/RTS2I: IC2.6 (A4), TP17.P$1; also elsewhere on the board
SARA_DTR/TXD2I: IC2.3 (A1), TP14.P$1; also elsewhere on the board
SARA_EXT_INT: JP19.3; also elsewhere on the board
SARA_GPIO3: JP19.1; also elsewhere on the board
SARA_INT: Q5.3 (D), R30.1, TP12.P$1; also elsewhere on the board
SARA_NI: R34.1; also elsewhere on the board
SARA_PWR_ON: Q2.3 (D); also elsewhere on the board
SARA_RI/CTS2O: IC2.5 (A3), TP16.P$1; also elsewhere on the board
SARA_RTS: IC1.6 (A4), TP4.P$1; also elsewhere on the board
SARA_RXD: IC1.3 (A1), TP1.P$1; also elsewhere on the board
SARA_SCL: U7.P6 (SCL2); also elsewhere on the board
SARA_SCL_1.8V: TP10.P$1, U7.P3 (SCL1); also elsewhere on the board
SARA_SDA: U7.P5 (SDA2); also elsewhere on the board
SARA_SDA_1.8V: TP9.P$1, U7.P4 (SDA1); also elsewhere on the board
SARA_TP: R32.1; also elsewhere on the board
SARA_TXD: IC1.4 (A2), TP2.P$1; also elsewhere on the board
TX1: IC1.13 (B2), TP6.P$1; also elsewhere on the board
VCCIO: C22.1, C23.1, DSR.3, IC1.1 (DIR1), IC1.7 (DIR3), IC1.16 (VCCA), IC2.2 (DIR2), IC2.7 (DIR3), IC2.16 (VCCA), Q5.1 (G), R29.2, R42.1, U7.P2 (VREF1); also elsewhere on the board
VIN: U3.1 (IN); also elsewhere on the board
V_BATT: U4.2 (CELL), U4.3 (VDD); also elsewhere on the board

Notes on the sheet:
Paul Clark
v11
Board thickness: 1.6mm
Er: 4.6
Copper Thickness (1oz): 1.4mil/0.035mm
RF Trace Width: 13.8mil/0.35mm
Polygon Isolation: 8mil/0.2032mm
Prepreg dielectric thickness (layer 1 to 2): 0.2mm
https://chemandy.com/calculators/coplanar-waveguide-with-ground-calculator.htm
Microstrip Calculation:
50Ω
LTE Antenna
GNSS Antenna
SARA Level Shifting
SARA LEDs
SARA ANT and ANT_GNSS pads do not require restrict on layer 2 as the prepreg thickness is >= 200µm
SARA-R5 VCC Design Notes:
VCC: Min. 3.3V Typ. 3.8V Max. 4.4V VCC Extended: Min. 3.0V Max. 4.5V Worst case: Maximum current draw during Tx: 395mA Estimated current for other components: 100mA Total maximum current draw: ~500mA AP7361C-33 drop out voltage: ~170mV at: 500mA output current; Vout = 3.3V; 25°C D7 LSM115J Schottky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
AP2112K-3.3V 3.3V @ 600mA Iq = 50µA
Battery Fuel Gauge
I2C Address = 0x36
Change jumper to reverse the direction of DSR for 2 UART communication
GNSS Active Antenna Power Enable
ANT_GNSS_PWR_EN is 1.8V (from SARA GPIO2). To minimise power draw when the SARA is OFF, ANT_REG_EN needs to be low when ANT_GNSS_PWR_EN is low.
SARA VCCIO is 1.8V

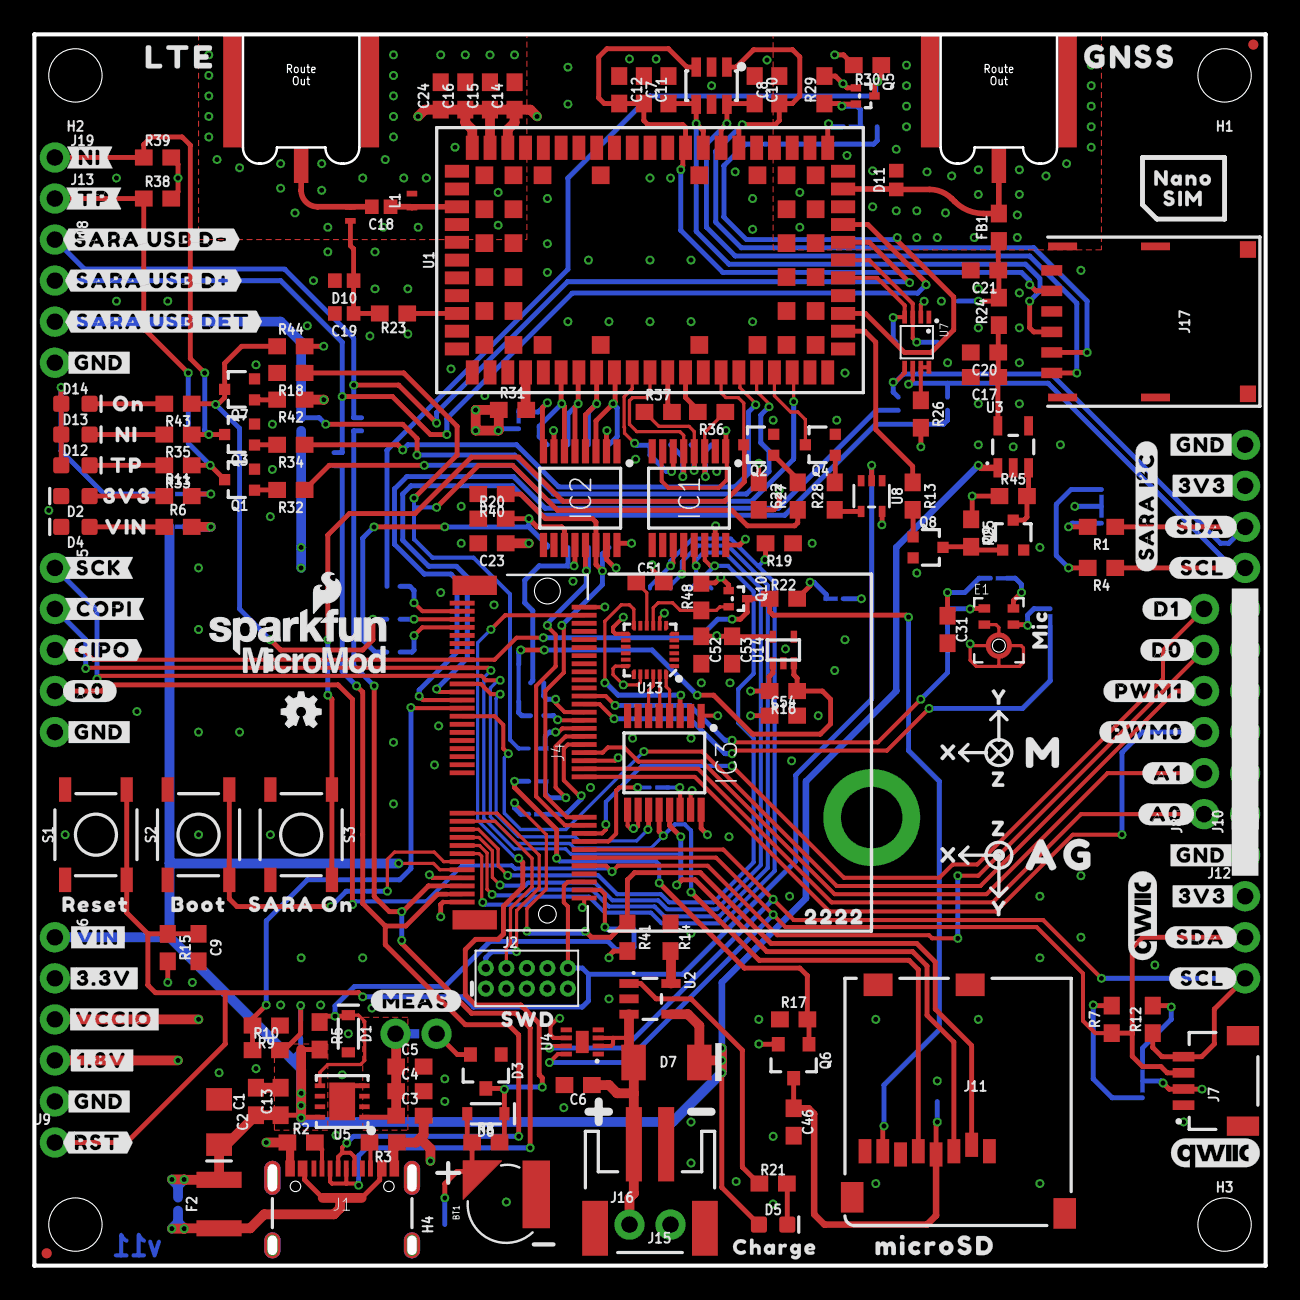
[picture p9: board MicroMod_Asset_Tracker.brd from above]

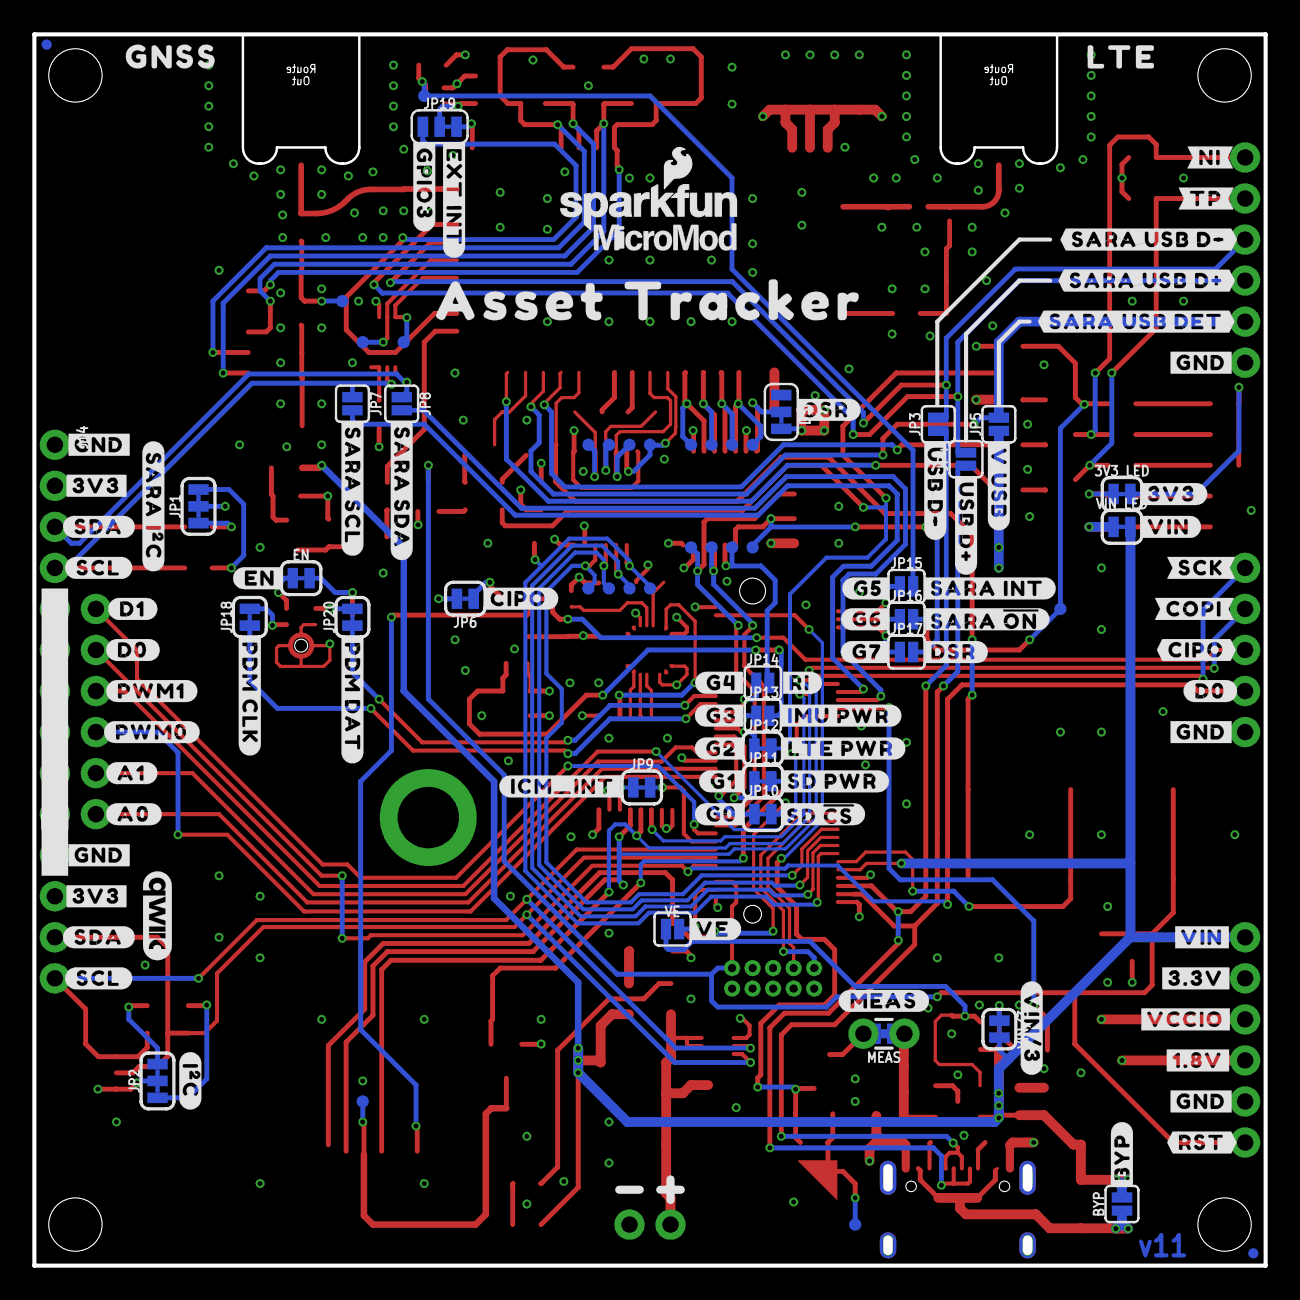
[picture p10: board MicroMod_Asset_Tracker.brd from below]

Board: 4 copper layers, 76.2 x 76.2 mm, 340 parts (128 on the bottom side), 137 nets.

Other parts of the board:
LOGO4: SFE_LOGO_NAME_FLAME.1_INCH; SFE_LOGO_NAME_FLAME_.1
LOGO6, LOGO7: QWIIC_LOGO_CONNECTOR; QWIIC_5.5MM
U$1: #EN#0
U$2: MIC0
U$3, U$11, U$13, U$14: #3V3#1
U$4: #3V3#0
U$5, U$23: #SARA_I�C#0
U$6, U$7: #A0#5
U$8, U$9: #A1#4
U$10, U$25, U$35, U$68: #D0#1
U$12, U$15, U$16, U$22: #GND#0
U$17, U$86: #RST#1
U$18: #VE#0
U$19, U$87: #MEAS#2
U$20: #VIN#1
U$21: SWD0
U$24, U$34: MICROMOD_LOGO_.35
U$26, U$27, U$43, U$44: #SCL#3
U$28: MICROSD0
U$29, U$31: #D1#0
U$30, U$37, U$50, U$51: #SDA#2
U$32, U$41: #PWM0#3
U$33: #BYP#1
U$36: 3V37
U$38, U$48: Y2
U$39, U$47: X1
U$40: BOOT5
U$42, U$49: #PWM1#2
U$45: RESET6
U$46: VIN8
U$52, U$54: Z0
U$53: #I�C#0
U$55, U$56, U$73, U$74, U$81, U$82: #GND#4
U$57, U$58: #TP#0
U$59, U$60: #NI#0
U$61, U$62, U$63, U$64: #SARA_USB_D##0
U$65, U$66: #SARA_USB_DET#0
U$67, U$75: #VIN#0
U$69, U$70: #CIPO#2
U$71, U$72: #COPI#1
U$76, U$79: #3#3V#0
U$77, U$78: #SCK#0
U$80, U$83: #VCCIO#0
U$84, U$85: #1#8V#0
U$88, U$89: LTE0
U$90: NI0
U$91: TP0
U$92, U$93: #USB_D##0
U$94: #V_USB#0
U$95: AG0
U$96: M0
U$97: CHARGE0
U$98: ASSET_TRACKER0
U$99, U$100: GNSS0
U$101: ON0
U$102, U$105: #DSR#0
U$103: #SARA_INT#0
U$104: #RI#0
U$106: #SD_#CS##0
U$107: #IMU_PWR#0
U$108: #LTE_PWR#0
U$109: #SD_PWR#0
U$110: #SARA_#ON##0
U$111: #SARA_SCL#0
U$112: #SARA_SDA#0
U$113: SARA_ON0
U$114: #CIPO#0
U$115: 22220
U$116: #PDM_CLK#0
U$117: #PDM_DAT#0
U$118: #EXT_INT#0
U$119: #GPIO3#0
U$122: #G0#0
U$123: #G1#0
U$124: #G2#0
U$125: #G3#0
U$126: #G4#0
U$127: #G7#0
U$128: #G6#0
U$129: #G5#0
U$130: NANO0
U$131: SIM0
U$133: #VIN#3#0
U$134: #ICM_INT#0

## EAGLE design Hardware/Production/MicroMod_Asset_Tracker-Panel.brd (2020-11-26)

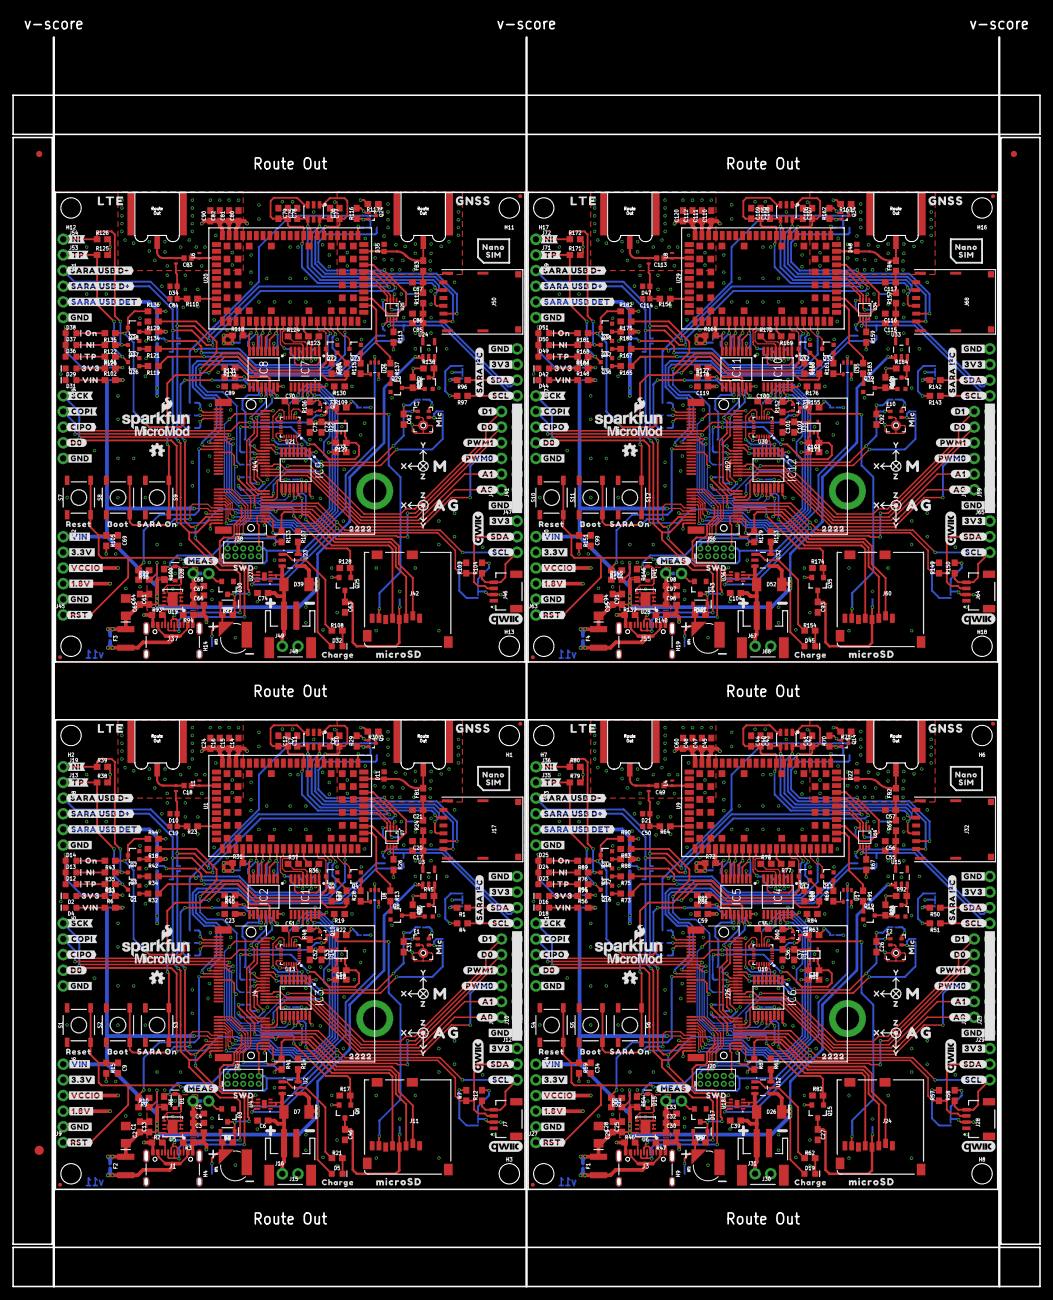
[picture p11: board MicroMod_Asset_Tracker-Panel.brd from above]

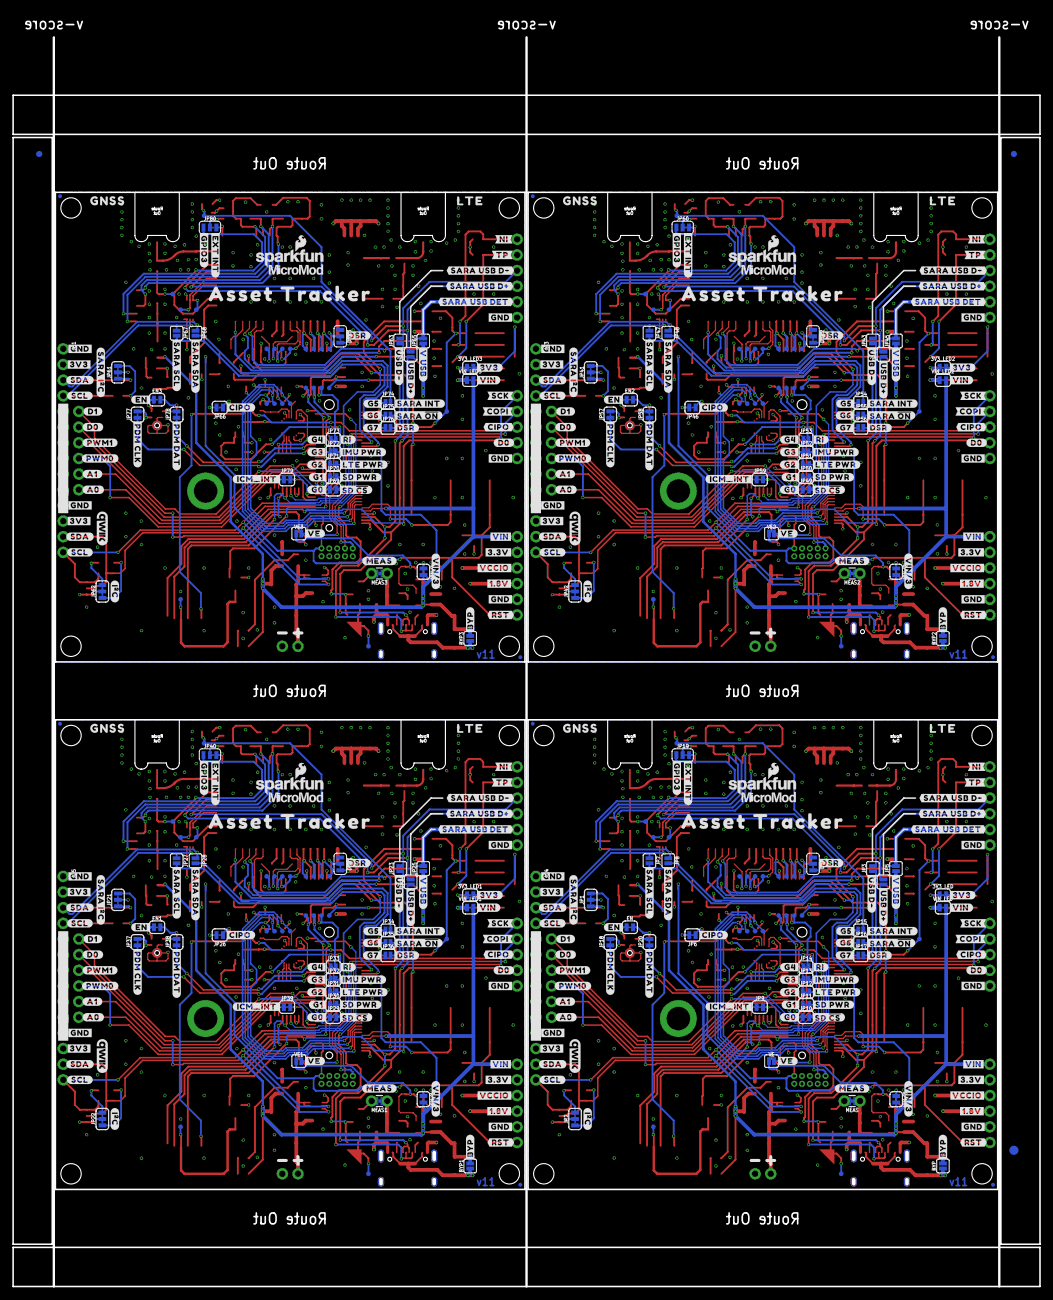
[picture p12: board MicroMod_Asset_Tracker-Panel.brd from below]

Board: 4 copper layers, 166.6 x 202.7 mm, 1354 parts (515 on the bottom side), 548 nets.

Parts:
3V3_LED, 3V3_LED1, 3V3_LED2, 3V3_LED3: SMT-JUMPER_2_NC_TRACE_SILK
BT1, BT2, BT3, BT4: ML414H; ML414H_IV01E
BYP, BYP1, BYP2, BYP3: JUMPER-SMT_2_NO_SILK; SMT-JUMPER_2_NO_SILK
C1, C4, C12, C14, C20, C22, C23, C26, C27, C28, C31, C32, C35, C36, C44, C45, C46, C51, C52, C56, C58, C59, C62, C63, C64, C67, C70, C71, C79, C80, C86, C88, C89, C92, C93, C94, C97, C100, C101, C109, C110, C116, C118, C119: 0.1uF; 0603
C2, C29, C65, C95: 10uF; EIA3216
C3, C6, C30, C39, C66, C74, C96, C104: 4.7uF; 0603
C5, C13, C25, C33, C61, C68, C91, C98: 0.22uF; 0603
C7, C8, C10, C11, C21, C40, C41, C42, C43, C57, C75, C76, C77, C78, C87, C105, C106, C107, C108, C117: 47pF; 0603
C9, C34, C69, C99: 1nF; 0603
C15, C47, C81, C111: 68pF; 0603
C16, C48, C82, C112: 10uF; 0603
C17, C37, C38, C53, C54, C55, C72, C73, C85, C102, C103, C115: 1.0uF; 0603
C18, C49, C83, C113: 33pF; 0402
C19, C50, C84, C114: 27pF; 0402
C24, C60, C90, C120: 15pF; 0603
D1, D15, D28, D41: 3.3V; SOD-323
D2, D16, D29, D42: RED; LED-0603
D3, D17, D30, D43: BAS70-05; SOT23-3
D4, D5, D18, D19, D31, D32, D44, D45: Yellow; LED-0603
D6, D9, D27, D40: 3A/10V/280mV; SOD-323
D7, D26, D39, D52: 1A/15V/220mV; DO-214BA
D8, D20, D33, D46: DT1042-04SO-7; SOT23-6L
D10, D11, D21, D22, D34, D35, D47, D48: PESD0402; 0402
D12, D23, D36, D49: GREEN; LED-0603
D13, D24, D37, D50: BLUE; LED-0603
D14, D25, D38, D51: WHITE; LED-0603
DSR, DSR1, DSR2, DSR3: JUMPER-SMT_3_1-NC_TRACE_SILK; SMT-JUMPER_3_1-NC_TRACE_SILK
E1, E2, E7, E10: SPH0641LM4H-1; SPH0641LM4H-1_MICROPHONE
E3, E5, E8, E11: LTE; SMA-EDGE-SMD
E4, E6, E9, E12: GNSS; SMA-EDGE-SMD
E$1, E$2, E$3, E$4: FIDUCIAL-1X2
E$5, E$6: FIDUCIAL-1.5X3
EN, EN1, EN2, EN3: SMT-JUMPER_2_NC_TRACE_SILK
F1, F2, F3, F4: 6V/2A; 1210
FB1, FB2, FB3, FB4: 30Ω/1.8A; 0603
FD1, FD2, FD3, FD4, FD5, FD6, FD7, FD8, FD9, FD10, FD11, FD12, FD13, FD14, FD15, FD16: FIDUCIALUFIDUCIAL; FIDUCIAL-MICRO
H1, H2, H3, H4, H6, H7, H8, H9, H11, H12, H13, H14, H16, H17, H18, H19: STAND-OFF
H5, H10, H15, H20: STAND-OFF-REFLOW2.5MM_TALL; STAND-OFF-REFLOW-M2.5
IC1, IC2, IC3, IC4, IC5, IC6, IC7, IC8, IC9, IC10, IC11, IC12: SN74AVC4T774PW; SOP65P640X120-16N
J1, J3, J37, J55: USB-C-16P_4LAYER-PADS
J2, J20, J38, J56: JTAG; 2X5-PTH-1.27MM
J4, J26, J44, J62: MICROMOD-2222-C; M.2-CONNECTOR-E
J5, J21, J39, J57: SPI; 1X05_NO_SILK
J6, J34, J52, J70: DIAG; 1X05_NO_SILK
J7, J28, J46, J64: QWIIC_RIGHT_ANGLE; JST04_1MM_RA
J8, J10, J22, J23, J40, J41, J58, J59: 1X06_NO_SILK
J9, J27, J45, J63: !RST!; 1X01_NO_SILK
J11, J24, J42, J60: microSD; MICRO-SD-SOCKET
J12, J14, J25, J29, J43, J47, J61, J65: 1X04_NO_SILK
J13, J35, J53, J71: TP; 1X01_NO_SILK
J15, J30, J48, J66: JST-2-SMD
J16, J31, J49, J67: 1X02_NO_SILK
J17, J32, J50, J68: NANO_SIM; NANO_SIM_WURTH_693043020611
J18, J33, J51, J69: SARA_USB; 1X04_NO_SILK
J19, J36, J54, J72: NI; 1X01_NO_SILK
JP1, JP2, JP21, JP22, JP41, JP42, JP61, JP62: SMT-JUMPER_3_2-NC_TRACE_SILK
JP3, JP4, JP5, JP7, JP8, JP13, JP14, JP15, JP16, JP17, JP23, JP24, JP25, JP27, JP28, JP32, JP33, JP34, JP35, JP36, JP43, JP44, JP45, JP47, JP48, JP52, JP53, JP54, JP55, JP56, JP63, JP64, JP65, JP67, JP68, JP72, JP73, JP74, JP75, JP76: JUMPER-SMT_2_NO_SILK; SMT-JUMPER_2_NO_SILK
JP6, JP9, JP10, JP11, JP12, JP18, JP20, JP26, JP29, JP30, JP31, JP37, JP38, JP39, JP46, JP49, JP50, JP51, JP57, JP58, JP59, JP66, JP69, JP70, JP71, JP77, JP78, JP79: JUMPER-SMT_2_NC_TRACE_SILK; SMT-JUMPER_2_NC_TRACE_SILK
JP19, JP40, JP60, JP80: JUMPER-SMT_3_1-NC_TRACE_SILK; SMT-JUMPER_3_1-NC_TRACE_SILK
L1, L4, L6, L8: DNP; 0402_COILCRAFT
L2, L3, L5, L7: 68nH; 0402_COILCRAFT
LOGO1, LOGO4, LOGO5, LOGO10, LOGO13, LOGO16, LOGO19, LOGO22: SFE_LOGO_NAME_FLAME.1_INCH; SFE_LOGO_NAME_FLAME_.1
LOGO2, LOGO6, LOGO7, LOGO8, LOGO11, LOGO12, LOGO14, LOGO17, LOGO18, LOGO20, LOGO23, LOGO24: QWIIC_LOGO_CONNECTOR; QWIIC_5.5MM
LOGO3, LOGO9, LOGO15, LOGO21: OSHW-LOGOMINI; OSHW-LOGO-MINI
MEAS, MEAS1, MEAS2, MEAS3: COMBO-JUMPER_2_NC_TRACE
Q1, Q2, Q3, Q4, Q7, Q8, Q9, Q12, Q13, Q16, Q17, Q18, Q19, Q20, Q22, Q23, Q26, Q27, Q28, Q29, Q30, Q32, Q33, Q36, Q37, Q38, Q39, Q40: 310mA/60V/1.6Ω; SOT323
Q5, Q10, Q11, Q14, Q21, Q24, Q31, Q34: 20V/0.2A/8MHz/1.2Ω/1Vth; SOT-416FL
Q6, Q15, Q25, Q35: 20V/4.2A/52mΩ/1.4W; SOT23-3
R1, R4, R7, R12, R14, R22, R29, R30, R48, R50, R51, R57, R58, R60, R61, R63, R70, R71, R96, R97, R103, R104, R106, R107, R109, R116, R117, R142, R143, R149, R150, R152, R153, R155, R162, R163: 2.2k; 0603
R2, R3, R46, R47, R93, R94, R139, R140: 5.1k; 0603
R5, R15, R16, R17, R18, R19, R20, R25, R38, R39, R40, R41, R44, R45, R54, R59, R66, R79, R80, R81, R82, R83, R84, R85, R86, R87, R90, R92, R100, R105, R112, R125, R126, R127, R128, R129, R130, R131, R132, R133, R136, R138, R146, R151, R158, R171, R172, R173, R174, R175, R176, R177, R178, R179, R182, R184: 100k; 0603
R6, R56, R102, R148: 4.7k; 0603
R8, R49, R95, R141: 3.3k; 0603
R9, R23, R52, R64, R98, R110, R144, R156: 10k; 0603
R10, R53, R99, R145: 20k; 0603
R11, R13, R21, R27, R28, R32, R34, R42, R43, R55, R62, R68, R69, R73, R75, R88, R89, R91, R101, R108, R114, R115, R119, R121, R134, R135, R137, R147, R154, R160, R161, R165, R167, R180, R181, R183: 1k; 0603
R24, R65, R111, R157: 10; 0603
R26, R67, R113, R159: 200k; 0603
R31, R36, R37, R72, R77, R78, R118, R123, R124, R164, R169, R170: 0; 0603
R33, R74, R120, R166: 100; 0603
R35, R76, R122, R168: 470; 0603
S1, S4, S7, S10: RESET; TACTILE_SWITCH_SMD_5.2MM
S2, S5, S8, S11: BOOT; TACTILE_SWITCH_SMD_5.2MM
S3, S6, S9, S12: SARA_PWR; TACTILE_SWITCH_SMD_5.2MM
TP1, TP2, TP3, TP4, TP5, TP6, TP7, TP8, TP9, TP10, TP11, TP12, TP13, TP14, TP15, TP16, TP17, TP18, TP19, TP20, TP21, TP22, TP23, TP24, TP25, TP26, TP27, TP28, TP29, TP30, TP31, TP32, TP33, TP34, TP35, TP36, TP37, TP38, TP39, TP40, TP41, TP42, TP43, TP44, TP45, TP46, TP47, TP48, TP49, TP50, TP51, TP52, TP53, TP54, TP55, TP56, TP57, TP58, TP59, TP60, TP61, TP62, TP63, TP64, TP65, TP66, TP67, TP68, TP69, TP70, TP71, TP72, TP73, TP74, TP75, TP76, TP77, TP78, TP79, TP80, TP81, TP82, TP83, TP84, TP85, TP86, TP87, TP88, TP89, TP90, TP91, TP92: TEST-POINT3; PAD.03X.03
U1, U9, U20, U29: SARA-R5; SARA-LGA
U2, U12, U23, U32: MCP73831; SOT23-5
U3, U15, U24, U33: 3.3V; SOT23-5
U4, U18, U27, U36: MAX17048; DFN-8
U5, U6, U19, U28: AP7361C-33FGE; UDFN-8
U7, U16, U25, U34: PCA9306; VSSOP_8PIN
U8, U17, U26, U35: 74HC1G04; SOT353
U10, U13, U21, U30: 9DoF IMU; QFN24-3X3-ICM-20948
U11, U14, U22, U31: 1.8V/100mA; SC70
U$1, U$223, U$354, U$485: #EN#0
U$2, U$222, U$353, U$484: MIC0
U$3, U$11, U$13, U$14, U$156, U$157, U$179, U$180, U$287, U$288, U$310, U$311, U$418, U$419, U$441, U$442: #3V3#1
U$4, U$176, U$307, U$438: #3V3#0
U$5, U$23, U$224, U$225, U$355, U$356, U$486, U$487: #SARA_I�C#0
U$6, U$7, U$144, U$145, U$275, U$276, U$406, U$407: #A0#5
U$8, U$9, U$146, U$147, U$277, U$278, U$408, U$409: #A1#4
U$10, U$25, U$35, U$68, U$148, U$149, U$254, U$255, U$279, U$280, U$385, U$386, U$410, U$411, U$516, U$517: #D0#1
U$12, U$15, U$16, U$22, U$158, U$159, U$181, U$182, U$289, U$290, U$312, U$313, U$420, U$421, U$443, U$444: #GND#0
U$17, U$86, U$174, U$211, U$305, U$342, U$436, U$473: #RST#1
U$18, U$175, U$306, U$437: #VE#0
U$19, U$87, U$171, U$212, U$302, U$343, U$433, U$474: #MEAS#2
U$20, U$177, U$308, U$439: #VIN#1
U$21, U$172, U$303, U$434: SWD0
U$24, U$34, U$120, U$121, U$263, U$264, U$394, U$395: MICROMOD_LOGO_.35
U$26, U$27, U$43, U$44, U$160, U$161, U$183, U$184, U$291, U$292, U$314, U$315, U$422, U$423, U$445, U$446: #SCL#3
U$28, U$178, U$309, U$440: MICROSD0
U$29, U$31, U$150, U$151, U$281, U$282, U$412, U$413: #D1#0
U$30, U$37, U$50, U$51, U$162, U$163, U$185, U$186, U$293, U$294, U$316, U$317, U$424, U$425, U$447, U$448: #SDA#2
U$32, U$41, U$152, U$153, U$283, U$284, U$414, U$415: #PWM0#3
U$33, U$173, U$304, U$435: #BYP#1
U$36, U$164, U$295, U$426: 3V37
U$38, U$48, U$169, U$188, U$300, U$319, U$431, U$450: Y2
U$39, U$47, U$168, U$189, U$299, U$320, U$430, U$451: X1
U$40, U$165, U$296, U$427: BOOT5
U$42, U$49, U$154, U$155, U$285, U$286, U$416, U$417: #PWM1#2
U$45, U$166, U$297, U$428: RESET6
U$46, U$167, U$298, U$429: VIN8
U$52, U$54, U$170, U$190, U$301, U$321, U$432, U$452: Z0
U$53, U$187, U$318, U$449: #I�C#0
U$55, U$56, U$73, U$74, U$81, U$82, U$138, U$139, U$142, U$143, U$191, U$192, U$269, U$270, U$273, U$274, U$322, U$323, U$400, U$401, U$404, U$405, U$453, U$454: #GND#4
U$57, U$58, U$193, U$194, U$324, U$325, U$455, U$456: #TP#0
U$59, U$60, U$195, U$196, U$326, U$327, U$457, U$458: #NI#0
U$61, U$62, U$63, U$64, U$197, U$198, U$199, U$200, U$328, U$329, U$330, U$331, U$459, U$460, U$461, U$462: #SARA_USB_D##0
U$65, U$66, U$201, U$202, U$332, U$333, U$463, U$464: #SARA_USB_DET#0
U$67, U$75, U$203, U$204, U$334, U$335, U$465, U$466: #VIN#0
U$69, U$70, U$132, U$135, U$265, U$266, U$396, U$397: #CIPO#2
U$71, U$72, U$136, U$137, U$267, U$268, U$398, U$399: #COPI#1
U$76, U$79, U$205, U$206, U$336, U$337, U$467, U$468: #3#3V#0
U$77, U$78, U$140, U$141, U$271, U$272, U$402, U$403: #SCK#0
U$80, U$83, U$207, U$208, U$338, U$339, U$469, U$470: #VCCIO#0
U$84, U$85, U$209, U$210, U$340, U$341, U$471, U$472: #1#8V#0
U$88, U$89, U$226, U$227, U$357, U$358, U$488, U$489: LTE0
U$90, U$213, U$344, U$475: NI0
U$91, U$214, U$345, U$476: TP0
U$92, U$93, U$215, U$216, U$346, U$347, U$477, U$478: #USB_D##0
U$94, U$217, U$348, U$479: #V_USB#0
U$95, U$218, U$349, U$480: AG0
U$96, U$219, U$350, U$481: M0
U$97, U$220, U$351, U$482: CHARGE0
U$98, U$221, U$352, U$483: ASSET_TRACKER0
U$99, U$100, U$228, U$229, U$359, U$360, U$490, U$491: GNSS0
U$101, U$242, U$373, U$504: ON0
U$102, U$105, U$232, U$245, U$363, U$376, U$494, U$507: #DSR#0
U$103, U$230, U$361, U$492: #SARA_INT#0
U$104, U$231, U$362, U$493: #RI#0
U$106, U$233, U$364, U$495: #SD_#CS##0
U$107, U$234, U$365, U$496: #IMU_PWR#0
U$108, U$235, U$366, U$497: #LTE_PWR#0
U$109, U$236, U$367, U$498: #SD_PWR#0
U$110, U$260, U$391, U$522: #SARA_#ON##0
U$111, U$237, U$368, U$499: #SARA_SCL#0
U$112, U$238, U$369, U$500: #SARA_SDA#0
U$113, U$241, U$372, U$503: SARA_ON0
U$114, U$239, U$370, U$501: #CIPO#0
U$115, U$240, U$371, U$502: 22220
U$116, U$243, U$374, U$505: #PDM_CLK#0
U$117, U$244, U$375, U$506: #PDM_DAT#0
U$118, U$261, U$392, U$523: #EXT_INT#0
U$119, U$262, U$393, U$524: #GPIO3#0
U$122, U$246, U$377, U$508: #G0#0
U$123, U$247, U$378, U$509: #G1#0
U$124, U$248, U$379, U$510: #G2#0
U$125, U$249, U$380, U$511: #G3#0
U$126, U$250, U$381, U$512: #G4#0
U$127, U$251, U$382, U$513: #G7#0
U$128, U$252, U$383, U$514: #G6#0
U$129, U$253, U$384, U$515: #G5#0
U$130, U$256, U$387, U$518: NANO0
U$131, U$257, U$388, U$519: SIM0
U$133, U$258, U$389, U$520: #VIN#3#0
U$134, U$259, U$390, U$521: #ICM_INT#0
VE, VE1, VE2, VE3: SMT-JUMPER_2_NO_SILK
VIN/1, VIN/2, VIN/3, VIN/4: JUMPER-SMT_2_NC_TRACE_SILK; SMT-JUMPER_2_NC_TRACE_SILK
VIN_LED, VIN_LED1, VIN_LED2, VIN_LED3: SMT-JUMPER_2_NC_TRACE_SILK

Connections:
1.8V: C52.1, C53.1, IC3.1, IC3.16, J6.4, Q10.1, R48.2, U13.8, U13.13, U14.5
1.8V1: C36.1, C37.1, IC6.1, IC6.16, J34.4, Q11.1, R60.2, U10.8, U10.13, U11.5
1.8V2: C71.1, C72.1, IC9.1, IC9.16, J52.4, Q21.1, R106.2, U21.8, U21.13, U22.5
1.8V3: C101.1, C102.1, IC12.1, IC12.16, J70.4, Q31.1, R152.2, U30.8, U30.13, U31.5
3.3V: 3V3_LED.2, C14.1, C15.1, C16.1, C24.1, C31.1, C54.1, D3.2, D12.A, D13.A, D14.A, EN.2, IC1.15, IC2.15, IC3.15, J2.1, J4.2, J4.74, J6.2, J7.2, J12.2, J14.2, JP1.2, JP2.2, JP6.2, MEAS.2, MEAS.4, Q6.2, R15.2, R16.2, R25.1, R26.2, R30.2, R38.2, R39.2, R41.2, R44.2, R45.1, U1.51, U1.52, U1.53, U8.5, U14.1
3.3V1: 3V3_LED1.2, C26.1, C38.1, C45.1, C47.1, C48.1, C60.1, D17.2, D23.A, D24.A, D25.A, EN1.2, IC4.15, IC5.15, IC6.15, J20.1, J25.2, J26.2, J26.74, J28.2, J29.2, J34.2, JP21.2, JP22.2, JP26.2, MEAS1.2, MEAS1.4, Q15.2, R59.2, R66.1, R67.2, R71.2, R79.2, R80.2, R81.2, R87.2, R90.2, R92.1, U9.51, U9.52, U9.53, U11.1, U17.5
3.3V2: 3V3_LED2.2, C62.1, C73.1, C80.1, C81.1, C82.1, C90.1, D30.2, D36.A, D37.A, D38.A, EN2.2, IC7.15, IC8.15, IC9.15, J38.1, J43.2, J44.2, J44.74, J46.2, J47.2, J52.2, JP41.2, JP42.2, JP46.2, MEAS2.2, MEAS2.4, Q25.2, R105.2, R112.1, R113.2, R117.2, R125.2, R126.2, R127.2, R133.2, R136.2, R138.1, U20.51, U20.52, U20.53, U22.1, U26.5
3.3V3: 3V3_LED3.2, C92.1, C103.1, C110.1, C111.1, C112.1, C120.1, D43.2, D49.A, D50.A, D51.A, EN3.2, IC10.15, IC11.15, IC12.15, J56.1, J61.2, J62.2, J62.74, J64.2, J65.2, J70.2, JP61.2, JP62.2, JP66.2, MEAS3.2, MEAS3.4, Q35.2, R151.2, R158.1, R159.2, R163.2, R171.2, R172.2, R173.2, R179.2, R182.2, R184.1, U29.51, U29.52, U29.53, U31.1, U35.5
3.3V_EN: J4.4, VE.1
3.3V_EN1: J26.4, VE1.1
3.3V_EN2: J44.4, VE2.1
3.3V_EN3: J62.4, VE3.1
!BOOT!: J4.11, S2.3, S2.4
!BOOT!1: J26.11, S5.3, S5.4
!BOOT!2: J44.11, S8.3, S8.4
!BOOT!3: J62.11, S11.3, S11.4
!RESET!: C9.1, J2.10, J4.6, J9.1, R15.1, S1.3, S1.4, U8.2
!RESET!1: C34.1, J20.10, J26.6, J27.1, R59.1, S4.3, S4.4, U17.2
!RESET!2: C69.1, J38.10, J44.6, J45.1, R105.1, S7.3, S7.4, U26.2
!RESET!3: C99.1, J56.10, J62.6, J63.1, R151.1, S10.3, S10.4, U35.2
A0: J4.34, J8.1
A1: J4.38, J8.2
A2: J22.1, J26.34
A3: J22.2, J26.38
A4: J40.1, J44.34
A5: J40.2, J44.38
A6: J58.1, J62.34
A7: J58.2, J62.38
ANT_GNSS_PWR_EN: R13.1, U1.23
ANT_GNSS_PWR_EN1: R91.1, U9.23
ANT_GNSS_PWR_EN2: R137.1, U20.23
ANT_GNSS_PWR_EN3: R183.1, U29.23
ANT_REG_EN: Q9.3, R45.2, U3.3
ANT_REG_EN1: Q20.3, R92.2, U15.3
ANT_REG_EN2: Q30.3, R138.2, U24.3
ANT_REG_EN3: Q40.3, R184.2, U33.3
CHG_LED: R21.1, U2.1
CHG_LED1: R62.1, U12.1
CHG_LED2: R108.1, U23.1
CHG_LED3: R154.1, U32.1
CTS1: IC1.12, J4.15, TP7.P$1
CTS2: IC4.12, J26.15, TP30.P$1
CTS3: IC7.12, J44.15, TP53.P$1
CTS4: IC10.12, J62.15, TP76.P$1
D0: J4.10, J5.4, J8.5
D1: J4.18, J8.6
D2: J22.6, J26.18
D3: J21.4, J22.5, J26.10
D4: J40.6, J44.18
D5: J39.4, J40.5, J44.10
D6: J58.6, J62.18
D7: J57.4, J58.5, J62.10
DCD: IC2.13, J4.20, TP19.P$1
DCD1: IC5.13, J26.20, TP40.P$1
DCD2: IC8.13, J44.20, TP63.P$1
DCD3: IC11.13, J62.20, TP86.P$1
DSR: IC2.11, JP17.2, R20.2, TP21.P$1
DSR1: IC5.11, JP36.2, R85.2, TP42.P$1
DSR2: IC8.11, JP56.2, R131.2, TP65.P$1
DSR3: IC11.11, JP76.2, R177.2, TP88.P$1
DTR: IC2.14, J4.22, R40.1, TP18.P$1
DTR1: IC5.14, J26.22, R86.1, TP39.P$1
DTR2: IC8.14, J44.22, R132.1, TP62.P$1
DTR3: IC11.14, J62.22, R178.1, TP85.P$1
G0: J4.40, JP10.1
G1: J4.42, JP11.1
G2: J4.44, JP12.1
G3: J4.46, JP13.1
G4: J4.48, JP14.1
G5: J4.73, JP15.1
G6: J4.71, JP16.1
G7: J4.69, JP17.1
G8: J26.40, JP29.1
G9: J26.42, JP30.1
G10: J26.44, JP31.1
G11: J26.46, JP32.1
G12: J26.48, JP33.1
G13: J26.73, JP34.1
G14: J26.71, JP35.1
G15: J26.69, JP36.1
G16: J44.40, JP49.1
G17: J44.42, JP50.1
G18: J44.44, JP51.1
G19: J44.46, JP52.1
G20: J44.48, JP53.1
G21: J44.73, JP54.1
G22: J44.71, JP55.1
G23: J44.69, JP56.1
G24: J62.40, JP69.1
G25: J62.42, JP70.1
G26: J62.44, JP71.1
G27: J62.46, JP72.1
G28: J62.48, JP73.1
G29: J62.73, JP74.1
G30: J62.71, JP75.1
G31: J62.69, JP76.1
GND: BT1.-, C1.2, C2.-, C3.2, C4.2, C5.2, C6.2, C7.2, C8.2, C9.2, C10.1, C11.1, C12.1, C13.2, C14.2, C15.2, C16.2, C17.2, C19.2, C20.2, C21.2, C22.2, C23.2, C24.2, C31.2, C46.2, C51.2, C52.2, C53.2, C54.2, D1.A, D2.C, D4.C, D8.2, D8.5, D10.2, D11.2, DSR.1, E1.2, E1.3, E1.6, E1.7, E1.8, E3.GND@0, E3.GND@1, E4.GND@0, E4.GND@1, H5.1, IC1.2, IC1.8, IC1.9, IC1.10, IC2.1, IC2.9, IC2.10, IC3.2, IC3.7, IC3.8, IC3.9, IC3.10, J1.GND, J1.GND2, J2.3, J2.5, J2.9, J4.1, J4.7, J4.33, J4.36, J4.39, J4.45, J4.75, J5.5, J6.5, J7.1, J10.1, J10.2, J10.3, J10.4, J10.5, J10.6, J11.CD1, J11.GND, J11.GND1, J11.GND3, J12.1, J14.1, J15.1, J16.2, J17.C5, J18.4, L1.P$2, Q1.2, Q2.2, Q3.2, Q4.2, Q7.2, Q8.2, Q9.2, R2.1, R3.1, R9.1, R14.1, R17.1, R18.2, R19.1, R20.1, R40.2, S1.1, S1.2, S2.1, S2.2, S3.3, S3.4, U1.1, U1.3, U1.5, U1.14, U1.20, U1.21, U1.22, U1.30, U1.32, U1.43, U1.50, U1.54, U1.55, U1.57, U1.58, U1.59, U1.60, U1.61, U1.63, U1.64, U1.65, U1.66, U1.67, U1.68, U1.69, U1.70, U1.71, U1.72, U1.73, U1.74, U1.75, U1.76, U1.77, U1.78, U1.79, U1.80, U1.81, U1.82, U1.83, U1.84, U1.85, U1.86, U1.87, U1.88, U1.89, U1.90, U1.91, U1.92, U1.93, U1.94, U1.95, U1.96, U2.2, U3.2, U4.1, U4.4, U4.6, U4.9, U5.4, U5.EP, U7.P1, U8.3, U13.18, U13.20, U14.2
GND1: BT2.-, C25.2, C26.2, C27.2, C28.2, C29.-, C30.2, C32.2, C33.2, C34.2, C35.2, C36.2, C37.2, C38.2, C39.2, C40.2, C41.2, C42.1, C43.1, C44.1, C45.2, C47.2, C48.2, C50.2, C55.2, C56.2, C57.2, C58.2, C59.2, C60.2, D15.A, D16.C, D18.C, D20.2, D20.5, D21.2, D22.2, DSR1.1, E2.2, E2.3, E2.6, E2.7, E2.8, E5.GND@0, E5.GND@1, E6.GND@0, E6.GND@1, H10.1, IC4.2, IC4.8, IC4.9, IC4.10, IC5.1, IC5.9, IC5.10, IC6.2, IC6.7, IC6.8, IC6.9, IC6.10, J3.GND, J3.GND2, J20.3, J20.5, J20.9, J21.5, J23.1, J23.2, J23.3, J23.4, J23.5, J23.6, J24.CD1, J24.GND, J24.GND1, J24.GND3, J25.1, J26.1, J26.7, J26.33, J26.36, J26.39, J26.45, J26.75, J28.1, J29.1, J30.1, J31.2, J32.C5, J33.4, J34.5, L4.P$2, Q12.2, Q13.2, Q16.2, Q17.2, Q18.2, Q19.2, Q20.2, R46.1, R47.1, R52.1, R61.1, R82.1, R83.2, R84.1, R85.1, R86.2, S4.1, S4.2, S5.1, S5.2, S6.3, S6.4, U6.4, U6.EP, U9.1, U9.3, U9.5, U9.14, U9.20, U9.21, U9.22, U9.30, U9.32, U9.43, U9.50, U9.54, U9.55, U9.57, U9.58, U9.59, U9.60, U9.61, U9.63, U9.64, U9.65, U9.66, U9.67, U9.68, U9.69, U9.70, U9.71, U9.72, U9.73, U9.74, U9.75, U9.76, U9.77, U9.78, U9.79, U9.80, U9.81, U9.82, U9.83, U9.84, U9.85, U9.86, U9.87, U9.88, U9.89, U9.90, U9.91, U9.92, U9.93, U9.94, U9.95, U9.96, U10.18, U10.20, U11.2, U12.2, U15.2, U16.P1, U17.3, U18.1, U18.4, U18.6, U18.9
GND2: BT3.-, C61.2, C62.2, C63.2, C64.2, C65.-, C66.2, C67.2, C68.2, C69.2, C70.2, C71.2, C72.2, C73.2, C74.2, C75.2, C76.2, C77.1, C78.1, C79.1, C80.2, C81.2, C82.2, C84.2, C85.2, C86.2, C87.2, C88.2, C89.2, C90.2, D28.A, D29.C, D31.C, D33.2, D33.5, D34.2, D35.2, DSR2.1, E7.2, E7.3, E7.6, E7.7, E7.8, E8.GND@0, E8.GND@1, E9.GND@0, E9.GND@1, H15.1, IC7.2, IC7.8, IC7.9, IC7.10, IC8.1, IC8.9, IC8.10, IC9.2, IC9.7, IC9.8, IC9.9, IC9.10, J37.GND, J37.GND2, J38.3, J38.5, J38.9, J39.5, J41.1, J41.2, J41.3, J41.4, J41.5, J41.6, J42.CD1, J42.GND, J42.GND1, J42.GND3, J43.1, J44.1, J44.7, J44.33, J44.36, J44.39, J44.45, J44.75, J46.1, J47.1, J48.1, J49.2, J50.C5, J51.4, J52.5, L6.P$2, Q22.2, Q23.2, Q26.2, Q27.2, Q28.2, Q29.2, Q30.2, R93.1, R94.1, R98.1, R107.1, R128.1, R129.2, R130.1, R131.1, R132.2, S7.1, S7.2, S8.1, S8.2, S9.3, S9.4, U19.4, U19.EP, U20.1, U20.3, U20.5, U20.14, U20.20, U20.21, U20.22, U20.30, U20.32, U20.43, U20.50, U20.54, U20.55, U20.57, U20.58, U20.59, U20.60, U20.61, U20.63, U20.64, U20.65, U20.66, U20.67, U20.68, U20.69, U20.70, U20.71, U20.72, U20.73, U20.74, U20.75, U20.76, U20.77, U20.78, U20.79, U20.80, U20.81, U20.82, U20.83, U20.84, U20.85, U20.86, U20.87, U20.88, U20.89, U20.90, U20.91, U20.92, U20.93, U20.94, U20.95, U20.96, U21.18, U21.20, U22.2, U23.2, U24.2, U25.P1, U26.3, U27.1, U27.4, U27.6, U27.9
GND3: BT4.-, C91.2, C92.2, C93.2, C94.2, C95.-, C96.2, C97.2, C98.2, C99.2, C100.2, C101.2, C102.2, C103.2, C104.2, C105.2, C106.2, C107.1, C108.1, C109.1, C110.2, C111.2, C112.2, C114.2, C115.2, C116.2, C117.2, C118.2, C119.2, C120.2, D41.A, D42.C, D44.C, D46.2, D46.5, D47.2, D48.2, DSR3.1, E10.2, E10.3, E10.6, E10.7, E10.8, E11.GND@0, E11.GND@1, E12.GND@0, E12.GND@1, H20.1, IC10.2, IC10.8, IC10.9, IC10.10, IC11.1, IC11.9, IC11.10, IC12.2, IC12.7, IC12.8, IC12.9, IC12.10, J55.GND, J55.GND2, J56.3, J56.5, J56.9, J57.5, J59.1, J59.2, J59.3, J59.4, J59.5, J59.6, J60.CD1, J60.GND, J60.GND1, J60.GND3, J61.1, J62.1, J62.7, J62.33, J62.36, J62.39, J62.45, J62.75, J64.1, J65.1, J66.1, J67.2, J68.C5, J69.4, J70.5, L8.P$2, Q32.2, Q33.2, Q36.2, Q37.2, Q38.2, Q39.2, Q40.2, R139.1, R140.1, R144.1, R153.1, R174.1, R175.2, R176.1, R177.1, R178.2, S10.1, S10.2, S11.1, S11.2, S12.3, S12.4, U28.4, U28.EP, U29.1, U29.3, U29.5, U29.14, U29.20, U29.21, U29.22, U29.30, U29.32, U29.43, U29.50, U29.54, U29.55, U29.57, U29.58, U29.59, U29.60, U29.61, U29.63, U29.64, U29.65, U29.66, U29.67, U29.68, U29.69, U29.70, U29.71, U29.72, U29.73, U29.74, U29.75, U29.76, U29.77, U29.78, U29.79, U29.80, U29.81, U29.82, U29.83, U29.84, U29.85, U29.86, U29.87, U29.88, U29.89, U29.90, U29.91, U29.92, U29.93, U29.94, U29.95, U29.96, U30.18, U30.20, U31.2, U32.2, U33.2, U34.P1, U35.3, U36.1, U36.4, U36.6, U36.9
I2C_SCL: J4.14, J7.4, J12.4, R12.1, U4.7
I2C_SCL1: J26.14, J28.4, J29.4, R58.1, U18.7
I2C_SCL2: J44.14, J46.4, J47.4, R104.1, U27.7
I2C_SCL3: J62.14, J64.4, J65.4, R150.1, U36.7
I2C_SDA: J4.12, J7.3, J12.3, R7.1, U4.8
I2C_SDA1: J26.12, J28.3, J29.3, R57.1, U18.8
I2C_SDA2: J44.12, J46.3, J47.3, R103.1, U27.8
I2C_SDA3: J62.12, J64.3, J65.3, R149.1, U36.8
I2S_SCK/PDM_CLK: E1.4, JP18.2
I2S_SCK/PDM_CLK1: E2.4, JP37.2
I2S_SCK/PDM_CLK2: E7.4, JP57.2
I2S_SCK/PDM_CLK3: E10.4, JP77.2
I2S_WS/PDM_DAT: E1.1, JP20.2
I2S_WS/PDM_DAT1: E2.1, JP38.2
I2S_WS/PDM_DAT2: E7.1, JP58.2
I2S_WS/PDM_DAT3: E10.1, JP78.2
ICM-20948-LV_!CS!: IC3.6, U13.22
ICM-20948-LV_!CS!1: IC6.6, U10.22
ICM-20948-LV_!CS!2: IC9.6, U21.22
ICM-20948-LV_!CS!3: IC12.6, U30.22
ICM-20948-LV_INT: IC3.3, U13.12
ICM-20948-LV_INT1: IC6.3, U10.12
ICM-20948-LV_INT2: IC9.3, U21.12
ICM-20948-LV_INT3: IC12.3, U30.12
ICM-20948-LV_SCK: IC3.5, U13.23
ICM-20948-LV_SCK1: IC6.5, U10.23
ICM-20948-LV_SCK2: IC9.5, U21.23
ICM-20948-LV_SCK3: IC12.5, U30.23
ICM-20948-LV_SDI: IC3.4, U13.24
ICM-20948-LV_SDI1: IC6.4, U10.24
ICM-20948-LV_SDI2: IC9.4, U21.24
ICM-20948-LV_SDI3: IC12.4, U30.24
ICM-20948-LV_SDO: Q10.2, R48.1, U13.9
ICM-20948-LV_SDO1: Q11.2, R60.1, U10.9
ICM-20948-LV_SDO2: Q21.2, R106.1, U21.9
ICM-20948-LV_SDO3: Q31.2, R152.1, U30.9
ICM_!CS!: IC3.11, J4.55
ICM_!CS!1: IC6.11, J26.55
ICM_!CS!2: IC9.11, J44.55
ICM_!CS!3: IC12.11, J62.55
ICM_INT: IC3.14, JP9.1
ICM_INT1: IC6.14, JP39.1
ICM_INT2: IC9.14, JP59.1
ICM_INT3: IC12.14, JP79.1
ICM_PWR: JP13.2, R16.1, U14.3
ICM_PWR1: JP32.2, R81.1, U11.3
ICM_PWR2: JP52.2, R127.1, U22.3
ICM_PWR3: JP72.2, R173.1, U31.3
LTE_PWR_ON: JP12.2, R18.1, R27.1
LTE_PWR_ON1: JP31.2, R68.1, R83.1
LTE_PWR_ON2: JP51.2, R114.1, R129.1
LTE_PWR_ON3: JP71.2, R160.1, R175.1
MICROSD_PWR: JP11.2, Q6.1, R17.2
MICROSD_PWR1: JP30.2, Q15.1, R82.2
MICROSD_PWR2: JP50.2, Q25.1, R128.2
MICROSD_PWR3: JP70.2, Q35.1, R174.2
unnamed: R6.2, VIN_LED.1
unnamed: JP1.3, R4.2
unnamed: JP1.1, R1.2
unnamed: E1.5, EN.1
unnamed: J4.53, JP7.2
unnamed: 3V3_LED.1, R11.2
unnamed: D2.A, R11.1
unnamed: D4.A, R6.1
unnamed: JP2.3, R12.2
unnamed: J1.A5, R2.2
unnamed: J1.B5, R3.2
unnamed: D1.C, R5.1, U5.5, VE.2
unnamed: JP2.1, R7.2
unnamed: BT1.+, D6.A, R8.1, TP24.P$1
unnamed: C18.2, E3.SIG, L2.P$2
unnamed: C19.1, D10.1, L2.P$1, R23.2
unnamed: J4.51, JP8.2
unnamed: R10.2, VIN/3.1
unnamed: J4.16, JP9.2
unnamed: R14.2, U2.5
unnamed: D5.C, R21.2
unnamed: R26.1, U7.P7, U7.P8
unnamed: DSR.2, IC2.8
unnamed: C17.1, C20.1, R24.1, U3.5
unnamed: C21.1, FB1.1, R24.2, TP22.P$1
unnamed: Q2.1, R27.2
unnamed: Q4.1, R28.2
unnamed: R28.1, U8.4
unnamed: JP6.1, R22.2
unnamed: C51.1, U13.10
unnamed: R31.2, U1.4
unnamed: Q1.1, R32.2
unnamed: J13.1, Q1.3, R33.1, R38.1
unnamed: D12.C, R33.2
unnamed: Q3.1, R34.2
unnamed: J19.1, Q3.3, R35.1, R39.1
unnamed: D13.C, R35.2
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

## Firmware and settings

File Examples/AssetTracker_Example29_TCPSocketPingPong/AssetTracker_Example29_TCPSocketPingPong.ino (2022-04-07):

/*

  MicroMod Asset Tracker Example
  ==============================

  Socket "Ping Pong" - TCP Data Transfers on multiple sockets

  Written by: Paul Clark
  Date: April 7th 2022

  This example demonstrates how to transfer data to and from an external Python "Echo Server" using multiple TCP sockets

  The PDP profile is read from NVM. Please make sure you have run examples 14 & 17 previously to set up the profile.

  Here's a quick how-to (assuming you are familiar with Python):
    Open up a Python editor on your computer
    Copy the Multi_TCP_Echo.py from the SARA-R5 Library GitHub repo Utils folder: https://github.com/sparkfun/SparkFun_u-blox_SARA-R5_Arduino_Library/tree/main/Utils
    Log in to your router
    Find your computer's local IP address (usually 192.168.0.something)
    Go into your router's Security / Port Forwarding settings:
      Create a new port forwarding rule
      The IP address is your local IP address
      Set the local port range to 1200-1206 (if you changed TCP_PORT_BASE, use that port number instead)
      Set the external port range to 1200-1206
      Set the protocol to TCP (or BOTH)
      Enable the rule
    This will open up a direct connection from the outside world, through your router, to ports 1200-1206 on your computer
      Remember to lock them down again when you're done!
    Edit the Python code and change 'HOST' to your local IP number:
      HOST = '192.168.0.nnn'
    Run the Python code
    Ask Google for your computer's public IP address:
      Google "what is my IP address"
    Run this code
    Enter your computer's public IP address when asked
    Sit back and watch the ping-pong!
    The code will stop after 20 Pings+Echos and 20 Pongs+Echos on each port
      On 5 ports, that's 400 TCP transfers in total!  

  The pins and ports are defined in AssetTrackerPins.ino.

  Please make sure that you have selected the correct Board using the Tools\Board menu:
  
  Please add these lines to your File\Preferences\Additional Boards Manager URLs:
  https://raw.githubusercontent.com/sparkfun/Arduino_Boards/master/IDE_Board_Manager/package_sparkfun_index.json
  https://raw.githubusercontent.com/espressif/arduino-esp32/gh-pages/package_esp32_index.json
  Then:
  SparkFun Artemis MicroMod: Click here to get the boards: http://boardsmanager/All#SparkFun_Apollo3
  SparkFun SAMD51 MicroMod : Click here to get the boards: http://boardsmanager/All#Arduino_SAMD_Boards plus http://boardsmanager/All#SparkFun_SAMD_Boards
  SparkFun ESP32 MicroMod  : Click here to get the boards: http://boardsmanager/All#ESP32 (Please install the Espressif ESP32 boards _and_ the SparkFun ESP32 boards)

  Feel like supporting open source hardware?
  Buy a board from SparkFun!
  SparkFun MicroMod Asset Tracker     : https://www.sparkfun.com/products/17272
  SparkFun MicroMod Artemis Processor : http://www.sparkfun.com/products/16401
  SparkFun MicroMod SAMD51 Processor  : http://www.sparkfun.com/products/16791
  SparkFun MicroMod ESP32 Processor   : http://www.sparkfun.com/products/16781

  Licence: MIT
  Please see LICENSE.md for full details

*/

#include "AssetTrackerPins.h" // Include the Asset Tracker pin and port definitions

#define SERIAL_PORT Serial // This is the console serial port - change this if required

//=-=-=-=-=-=-=-=-=-=-=-=-=-=-=-=-=-=-=-=-=-=-=-=-=-=-=-=-=-=-=-=-=-=-=-=-=-=-=-=-=-=-=-=-=

#include <SparkFun_u-blox_SARA-R5_Arduino_Library.h> //Click here to get the library: http://librarymanager/All#SparkFun_u-blox_SARA-R5_Arduino_Library

// Create a SARA_R5 object to use throughout the sketch. Pass it the power pin number.
SARA_R5 assetTracker(SARA_PWR);

//=-=-=-=-=-=-=-=-=-=-=-=-=-=-=-=-=-=-=-=-=-=-=-=-=-=-=-=-=-=-=-=-=-=-=-=-=-=-=-=-=-=-=-=-=

// Globals

const int numConnections = 5; // How many sockets do you want to use? Max is 7.
unsigned int TCP_PORT_BASE = 1200; // Change this if required

// Keep track of how many ping-pong exchanges have taken place. "Ping" closes the socket when pingCount reaches pingPongLimit.
volatile int pingCount[numConnections];
volatile int pongCount[numConnections];
const int pingPongLimit = 20;

// Keep track of how long the socket has been open. "Pong" closes the socket when timeLimit (millis) is reached.
unsigned long startTime;
const unsigned long timeLimit = 120000; // 120 seconds

#include <IPAddress.h> // Needed for sockets
volatile int socketNum[numConnections]; // Record the socket numbers. -1 indicates the socket is invalid or closed.

// =-=-=-=-=-=-=-=-=-=-=-=-=-=-=-=-=-=-=-=-=-=-=-=-=-=-=-=-=-=-=-=-=-=-=-=-=-=-=-=-=-=-=-=-=-=-=-=-=-=-=-=-=-=-=-=-=-=-=-=-

// processSocketListen is provided to the SARA-R5 library via a 
// callback setter -- setSocketListenCallback. (See setup())
void processSocketListen(int listeningSocket, IPAddress localIP, unsigned int listeningPort, int socket, IPAddress remoteIP, unsigned int port)
{
  SERIAL_PORT.println();
  SERIAL_PORT.print(F("Socket connection made: listeningSocket "));
  SERIAL_PORT.print(listeningSocket);
  SERIAL_PORT.print(F(" localIP "));
  SERIAL_PORT.print(localIP[0]);
  SERIAL_PORT.print(F("."));
  SERIAL_PORT.print(localIP[1]);
  SERIAL_PORT.print(F("."));
  SERIAL_PORT.print(localIP[2]);
  SERIAL_PORT.print(F("."));
  SERIAL_PORT.print(localIP[3]);
  SERIAL_PORT.print(F(" listeningPort "));
  SERIAL_PORT.print(listeningPort);
  SERIAL_PORT.print(F(" socket "));
  SERIAL_PORT.print(socket);
  SERIAL_PORT.print(F(" remoteIP "));
  SERIAL_PORT.print(remoteIP[0]);
  SERIAL_PORT.print(F("."));
  SERIAL_PORT.print(remoteIP[1]);
  SERIAL_PORT.print(F("."));
  SERIAL_PORT.print(remoteIP[2]);
  SERIAL_PORT.print(F("."));
  SERIAL_PORT.print(remoteIP[3]);
  SERIAL_PORT.print(F(" port "));
  SERIAL_PORT.println(port);
}

// =-=-=-=-=-=-=-=-=-=-=-=-=-=-=-=-=-=-=-=-=-=-=-=-=-=-=-=-=-=-=-=-=-=-=-=-=-=-=-=-=-=-=-=-=-=-=-=-=-=-=-=-=-=-=-=-=-=-=-=-

// processSocketData is provided to the SARA-R5 library via a 
// callback setter -- setSocketReadCallback. (See setup())
void processSocketData(int socket, String theData)
{
  int connection = -1;
  for (int i = 0; i < numConnections; i++)
    if (socketNum[i] == socket)
      connection = i;

  if (connection == -1)
  {
    SERIAL_PORT.println();
    SERIAL_PORT.print(F("Data received on unexpected socket "));
    SERIAL_PORT.println(socket);
    return;
  }
  
  SERIAL_PORT.println();
  SERIAL_PORT.print(F("Data received on socket "));
  SERIAL_PORT.print(socket);
  SERIAL_PORT.print(F(" : "));
  SERIAL_PORT.println(theData);
  
  if (theData == String("Ping")) // Look for the "Ping"
  {
    if (pongCount[connection] < pingPongLimit)
    {
      const char pong[] = "Pong";
      assetTracker.socketWrite(socket, pong); // Send the "Pong"
      pongCount[connection]++;
    }
  }

  if (theData == String("Pong")) // Look for the "Pong"
  {
    if (pingCount[connection] < pingPongLimit)
    {
      const char ping[] = "Ping";
      assetTracker.socketWrite(socket, ping); // Send the "Ping"
      pingCount[connection]++;
    }
  }

  SERIAL_PORT.print(F("pingCount = "));
  SERIAL_PORT.print(pingCount[connection]);
  SERIAL_PORT.print(F(" : pongCount = "));
  SERIAL_PORT.println(pongCount[connection]);
}

// =-=-=-=-=-=-=-=-=-=-=-=-=-=-=-=-=-=-=-=-=-=-=-=-=-=-=-=-=-=-=-=-=-=-=-=-=-=-=-=-=-=-=-=-=-=-=-=-=-=-=-=-=-=-=-=-=-=-=-=-

// processSocketClose is provided to the SARA-R5 library via a 
// callback setter -- setSocketCloseCallback. (See setup())
// 
// Note: the SARA-R5 only sends a +UUSOCL URC when the socket os closed by the remote
void processSocketClose(int socket)
{
  SERIAL_PORT.println();
  SERIAL_PORT.print(F("Socket "));
  SERIAL_PORT.print(socket);
  SERIAL_PORT.println(F(" closed!"));
}

// =-=-=-=-=-=-=-=-=-=-=-=-=-=-=-=-=-=-=-=-=-=-=-=-=-=-=-=-=-=-=-=-=-=-=-=-=-=-=-=-=-=-=-=-=-=-=-=-=-=-=-=-=-=-=-=-=-=-=-=-

// processPSDAction is provided to the SARA-R5 library via a 
// callback setter -- setPSDActionCallback. (See setup())
void processPSDAction(int result, IPAddress ip)
{
  SERIAL_PORT.println();
  SERIAL_PORT.print(F("PSD Action:  result: "));
  SERIAL_PORT.print(String(result));
  if (result == 0)
    SERIAL_PORT.print(F(" (success)"));
  SERIAL_PORT.print(F("  IP Address: \""));
  SERIAL_PORT.print(String(ip[0]));
  SERIAL_PORT.print(F("."));
  SERIAL_PORT.print(String(ip[1]));
  SERIAL_PORT.print(F("."));
  SERIAL_PORT.print(String(ip[2]));
  SERIAL_PORT.print(F("."));
  SERIAL_PORT.print(String(ip[3]));
  SERIAL_PORT.println(F("\""));
}

// =-=-=-=-=-=-=-=-=-=-=-=-=-=-=-=-=-=-=-=-=-=-=-=-=-=-=-=-=-=-=-=-=-=-=-=-=-=-=-=-=-=-=-=-=-=-=-=-=-=-=-=-=-=-=-=-=-=-=-=-

void setup()
{
  initializeAssetTrackerPins(); // Initialize the pins and ports (defined in AssetTrackerPins.ino)
  
  SERIAL_PORT.begin(115200); // Start the serial console

  // Wait for user to press key to begin
  SERIAL_PORT.println(F("SARA-R5 Example"));
  SERIAL_PORT.println(F("Wait for the SARA NI LED to light up - then press any key to begin"));
  
  while (!SERIAL_PORT.available()) // Wait for the user to press a key (send any serial character)
    ;
  while (SERIAL_PORT.available()) // Empty the serial RX buffer
    SERIAL_PORT.read();

  //=-=-=-=-=-=-=-=-=-=-=-=-=-=-=-=-=-=-=-=-=-=-=-=-=-=-=-=-=-=-=-=-=-=-=-=-=-=-=-=-=-=-=-=-=

  // Start communication with the SARA-R5. Load and activate the Packet Switched Data profile.

  //assetTracker.enableDebugging(); // Uncomment this line to enable helpful debug messages on Serial

  // For the MicroMod Asset Tracker, we need to invert the power pin so it pulls high instead of low
  // Comment the next line if required
  assetTracker.invertPowerPin(true); 

  // Initialize the SARA
    if (assetTracker.begin(SARA_Serial, 115200) )
  {
    SERIAL_PORT.println(F("SARA-R5 connected!"));
  }
  else
  {
    SERIAL_PORT.println(F("Unable to communicate with the SARA."));
    SERIAL_PORT.println(F("Manually power-on (hold the SARA On button for 3 seconds) on and try again."));
    while (1) ; // Loop forever on fail
  }
  SERIAL_PORT.println();

  // First check to see if we're connected to an operator:
  String currentOperator = "";
  if (assetTracker.getOperator(&currentOperator) == SARA_R5_SUCCESS)
  {
    SERIAL_PORT.print(F("Connected to: "));
    SERIAL_PORT.println(currentOperator);
  }
  else
  {
    SERIAL_PORT.print(F("The SARA is not yet connected to an operator. Please use the previous examples to connect. Or wait and retry. Freezing..."));
    while (1)
      ; // Do nothing more
  }

  // Deactivate the PSD profile - in case one is already active
  if (assetTracker.performPDPaction(0, SARA_R5_PSD_ACTION_DEACTIVATE) != SARA_R5_SUCCESS)
  {
    SERIAL_PORT.println(F("Warning: performPDPaction (deactivate profile) failed. Probably because no profile was active."));
  }

  // Load the PSD profile from NVM - these were saved by a previous example
  if (assetTracker.performPDPaction(0, SARA_R5_PSD_ACTION_LOAD) != SARA_R5_SUCCESS)
  {
    SERIAL_PORT.println(F("performPDPaction (load from NVM) failed! Freezing..."));
    while (1)
      ; // Do nothing more
  }

  // Activate the profile
  if (assetTracker.performPDPaction(0, SARA_R5_PSD_ACTION_ACTIVATE) != SARA_R5_SUCCESS)
  {
    SERIAL_PORT.println(F("performPDPaction (activate profile) failed! Freezing..."));
    while (1)
      ; // Do nothing more
  }

  //=-=-=-=-=-=-=-=-=-=-=-=-=-=-=-=-=-=-=-=-=-=-=-=-=-=-=-=-=-=-=-=-=-=-=-=-=-=-=-=-=-=-=-=-=

  //Print the dynamic IP Address (for profile 0)
  IPAddress myAddress;
  assetTracker.getNetworkAssignedIPAddress(0, &myAddress);
  SERIAL_PORT.print(F("\r\nMy IP Address is: "));
  SERIAL_PORT.print(myAddress[0]);
  SERIAL_PORT.print(F("."));
  SERIAL_PORT.print(myAddress[1]);
  SERIAL_PORT.print(F("."));
  SERIAL_PORT.print(myAddress[2]);
  SERIAL_PORT.print(F("."));
  SERIAL_PORT.println(myAddress[3]);

  //=-=-=-=-=-=-=-=-=-=-=-=-=-=-=-=-=-=-=-=-=-=-=-=-=-=-=-=-=-=-=-=-=-=-=-=-=-=-=-=-=-=-=-=-=

  for (int i = 0; i < numConnections; i++) // Reset the ping and pong counts
  {
    pingCount[i] = 0;
    pongCount[i] = 0;
  }

  //=-=-=-=-=-=-=-=-=-=-=-=-=-=-=-=-=-=-=-=-=-=-=-=-=-=-=-=-=-=-=-=-=-=-=-=-=-=-=-=-=-=-=-=-=

  // Set a callback to process the socket listen
  assetTracker.setSocketListenCallback(&processSocketListen);
  
  //=-=-=-=-=-=-=-=-=-=-=-=-=-=-=-=-=-=-=-=-=-=-=-=-=-=-=-=-=-=-=-=-=-=-=-=-=-=-=-=-=-=-=-=-=

  // Set a callback to process the socket data
  assetTracker.setSocketReadCallback(&processSocketData);
  
  //=-=-=-=-=-=-=-=-=-=-=-=-=-=-=-=-=-=-=-=-=-=-=-=-=-=-=-=-=-=-=-=-=-=-=-=-=-=-=-=-=-=-=-=-=

  // Set a callback to process the socket close
  // 
  // Note: the SARA-R5 only sends a +UUSOCL URC when the socket os closed by the remote
  assetTracker.setSocketCloseCallback(&processSocketClose);
  
  //=-=-=-=-=-=-=-=-=-=-=-=-=-=-=-=-=-=-=-=-=-=-=-=-=-=-=-=-=-=-=-=-=-=-=-=-=-=-=-=-=-=-=-=-=

  SERIAL_PORT.println(F("\r\nPlease enter the IP number you want to ping (nnn.nnn.nnn.nnn followed by LF / Newline): "));

  char c = 0;
  bool selected = false;
  int val = 0;
  IPAddress theAddress = {0,0,0,0};
  int field = 0;
  while (!selected)
  {
    while (!SERIAL_PORT.available()) ; // Wait for a character to arrive
    c = SERIAL_PORT.read(); // Read it
    if (c == '\n') // Is it a LF?
    {
      theAddress[field] = val; // Store the current value
      if (field == 3)
        selected = true;
      else
      {
        SERIAL_PORT.println(F("Invalid IP Address. Please try again:"));
        val = 0;
        field = 0;
      }
    }
    else if (c == '.') // Is it a separator
    {
      theAddress[field] = val; // Store the current value
      if (field <= 2)
        field++; // Increment the field
      val = 0; // Reset the value
    }
    else if ((c >= '0') && (c <= '9'))
    {
      val *= 10; // Multiply by 10
      val += c - '0'; // Add the digit
    }
  }

  SERIAL_PORT.print(F("Remote address is "));
  SERIAL_PORT.print(theAddress[0]);
  SERIAL_PORT.print(F("."));
  SERIAL_PORT.print(theAddress[1]);
  SERIAL_PORT.print(F("."));
  SERIAL_PORT.print(theAddress[2]);
  SERIAL_PORT.print(F("."));
  SERIAL_PORT.println(theAddress[3]);
  
  // Open the sockets
  for (int i = 0; i < numConnections; i++)
  {

    socketNum[i] = assetTracker.socketOpen(SARA_R5_TCP);
    if (socketNum[i] == -1)
    {
      SERIAL_PORT.println(F("socketOpen failed! Freezing..."));
      while (1)
        assetTracker.bufferedPoll(); // Do nothing more except process any received data
    }

    SERIAL_PORT.print(F("Connection "));
    SERIAL_PORT.print(i);
    SERIAL_PORT.print(F(" is using socket "));
    SERIAL_PORT.println(socketNum[i]);

    // Connect to the remote IP Address
    if (assetTracker.socketConnect(socketNum[i], theAddress, TCP_PORT_BASE + i) != SARA_R5_SUCCESS)
    {
      SERIAL_PORT.println(F("socketConnect failed! Freezing..."));
      while (1)
        assetTracker.bufferedPoll(); // Do nothing more except process any received data
    }
    else
    {
      SERIAL_PORT.println(F("Socket connected!"));
    }

    // Send the first ping to start the ping-pong
    const char ping[] = "Ping";
    assetTracker.socketWrite(socketNum[i], ping); // Send the "Ping"
  }
}

// =-=-=-=-=-=-=-=-=-=-=-=-=-=-=-=-=-=-=-=-=-=-=-=-=-=-=-=-=-=-=-=-=-=-=-=-=-=-=-=-=-=-=-=-=-=-=-=-=-=-=-=-=-=-=-=-=-=-=-=-

void loop()
{
  assetTracker.bufferedPoll(); // Process the backlog (if any) and any fresh serial data

  for (int i = 0; i < numConnections; i++)
  {
    // Close the socket when we've reached pingPongLimit
    if ((pingCount[i] >= pingPongLimit) && (socketNum[i] >= 0))
    {
      printSocketParameters(socketNum[i]);
      
      //Comment the next line if you want the remote to close the sockets when they timeout
      //assetTracker.socketClose(socketNum[i]); // Close the socket
      
      socketNum[i] = -1;
    }
  }
}

// =-=-=-=-=-=-=-=-=-=-=-=-=-=-=-=-=-=-=-=-=-=-=-=-=-=-=-=-=-=-=-=-=-=-=-=-=-=-=-=-=-=-=-=-=-=-=-=-=-=-=-=-=-=-=-=-=-=-=-=-

// Print the socket parameters
// Note: the socket must be open. ERRORs will be returned if the socket is closed.
void printSocketParameters(int socket)
{
  SERIAL_PORT.print(F("\r\nSocket parameters for socket: "));
  SERIAL_PORT.println(socket);
  
  SERIAL_PORT.print(F("Socket type: "));
  SARA_R5_socket_protocol_t socketType;
  assetTracker.querySocketType(socket, &socketType);
  if (socketType == SARA_R5_TCP)
    SERIAL_PORT.println(F("TCP"));
  else if (socketType == SARA_R5_UDP)
    SERIAL_PORT.println(F("UDP"));
  else
    SERIAL_PORT.println(F("UNKNOWN! (Error!)"));
  
  SERIAL_PORT.print(F("Last error: "));
  int lastError;
  assetTracker.querySocketLastError(socket, &lastError);
  SERIAL_PORT.println(lastError);
  
  SERIAL_PORT.print(F("Total bytes sent: "));
  uint32_t bytesSent;
  assetTracker.querySocketTotalBytesSent(socket, &bytesSent);
  SERIAL_PORT.println(bytesSent);
  
  SERIAL_PORT.print(F("Total bytes received: "));
  uint32_t bytesReceived;
  assetTracker.querySocketTotalBytesReceived(socket, &bytesReceived);
  SERIAL_PORT.println(bytesReceived);
  
  SERIAL_PORT.print(F("Remote IP Address: "));
  IPAddress remoteAddress;
  int remotePort;
  assetTracker.querySocketRemoteIPAddress(socket, &remoteAddress, &remotePort);
  SERIAL_PORT.print(remoteAddress[0]);
  SERIAL_PORT.print(F("."));
  SERIAL_PORT.print(remoteAddress[1]);
  SERIAL_PORT.print(F("."));
  SERIAL_PORT.print(remoteAddress[2]);
  SERIAL_PORT.print(F("."));
  SERIAL_PORT.println(remoteAddress[3]);

  SERIAL_PORT.print(F("Socket status (TCP sockets only): "));
  SARA_R5_tcp_socket_status_t socketStatus;
  assetTracker.querySocketStatusTCP(socket, &socketStatus);
  if (socketStatus == SARA_R5_TCP_SOCKET_STATUS_INACTIVE)
    SERIAL_PORT.println(F("INACTIVE"));
  else if (socketStatus == SARA_R5_TCP_SOCKET_STATUS_LISTEN)
    SERIAL_PORT.println(F("LISTEN"));
  else if (socketStatus == SARA_R5_TCP_SOCKET_STATUS_SYN_SENT)
    SERIAL_PORT.println(F("SYN_SENT"));
  else if (socketStatus == SARA_R5_TCP_SOCKET_STATUS_SYN_RCVD)
    SERIAL_PORT.println(F("SYN_RCVD"));
  else if (socketStatus == SARA_R5_TCP_SOCKET_STATUS_ESTABLISHED)
    SERIAL_PORT.println(F("ESTABLISHED"));
  else if (socketStatus == SARA_R5_TCP_SOCKET_STATUS_FIN_WAIT_1)
    SERIAL_PORT.println(F("FIN_WAIT_1"));
  else if (socketStatus == SARA_R5_TCP_SOCKET_STATUS_FIN_WAIT_2)
    SERIAL_PORT.println(F("FIN_WAIT_2"));
  else if (socketStatus == SARA_R5_TCP_SOCKET_STATUS_CLOSE_WAIT)
    SERIAL_PORT.println(F("CLOSE_WAIT"));
  else if (socketStatus == SARA_R5_TCP_SOCKET_STATUS_CLOSING)
    SERIAL_PORT.println(F("CLOSING"));
  else if (socketStatus == SARA_R5_TCP_SOCKET_STATUS_LAST_ACK)
    SERIAL_PORT.println(F("LAST_ACK"));
  else if (socketStatus == SARA_R5_TCP_SOCKET_STATUS_TIME_WAIT)
    SERIAL_PORT.println(F("TIME_WAIT"));
  else
    SERIAL_PORT.println(F("UNKNOWN! (Error!)"));
      
  SERIAL_PORT.print(F("Unacknowledged outgoing bytes: "));
  uint32_t bytesUnack;
  assetTracker.querySocketOutUnackData(socket, &bytesUnack);
  SERIAL_PORT.println(bytesUnack);
}

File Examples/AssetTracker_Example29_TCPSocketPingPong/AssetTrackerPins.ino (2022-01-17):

/*

  MicroMod Asset Tracker Pin & Port Support Functions
  ===================================================

  Written by: Paul Clark
  Date: December 28th 2021

  The file defines the pins and ports for the MicroMod Asset Tracker.

  The pin and ports are defined using the MicroMod naming scheme.
  This allows the code to run on different MicroMod Processor Boards
  without needing to change the pin numbers.

  Licence: MIT
  Please see the LICENSE.md for full details

*/

// Initialize the I/O pins.
// Default to having everything turned off.
// See below for the enable/disable functions.
void initializeAssetTrackerPins()
{
  pinMode(LED_BUILTIN, OUTPUT);
  digitalWrite(LED_BUILTIN, LOW);
  
  disableMicroSDPower();

  disableIMUPower();

  disableSPIPins();

  digitalWrite(SARA_PWR, LOW); // Make sure SARA_PWR is low before making the pin an output
  pinMode(SARA_PWR, OUTPUT);
  digitalWrite(SARA_PWR, LOW);

  pinMode(SARA_RI, INPUT);
  
  pinMode(SARA_INT, INPUT);

  if (SARA_DSR >= 0) pinMode(SARA_DSR, INPUT);

  if (SARA_ON >= 0) pinMode(SARA_ON, INPUT);

  pinMode(IMU_INT, INPUT);

  pinMode(VIN_DIV_3, INPUT);

}

// Disable SPI pins - to avoid parasitic power leaking throug the SD card
void disableSPIPins()
{
  pinMode(MICROSD_CS, OUTPUT);
  digitalWrite(MICROSD_CS, LOW); // Pull CS low to reduce current leak through the SD card
  pinMode(IMU_CS, OUTPUT);
  digitalWrite(IMU_CS, LOW); // Pull CS low to reduce sleep current
  pinMode(MISO, OUTPUT);
  digitalWrite(MISO, LOW); // Pull MISO low to reduce current leak through the SD card
  pinMode(MOSI, OUTPUT);
  digitalWrite(MOSI, LOW); // Pull MOSI low to reduce current leak through the SD card
  pinMode(SCK, OUTPUT);
  digitalWrite(SCK, LOW); // Pull SCK low to reduce current leak through the SD card
}
// Disable power for the micro SD card
void disableMicroSDPower()
{
  pinMode(MICROSD_PWR_EN, OUTPUT); // Define the pinMode here in case a sleep function has disabled it
  digitalWrite(MICROSD_PWR_EN, HIGH);
}
// Enable power for the micro SD card
void enableMicroSDPower()
{
  pinMode(MICROSD_PWR_EN, OUTPUT); // Define the pinMode here in case a sleep function has disabled it
  digitalWrite(MICROSD_PWR_EN, LOW);
  pinMode(MICROSD_CS, OUTPUT);
  digitalWrite(MICROSD_CS, HIGH); // Pull CS high to disable the SD card
}

// Disable power for the IMU
void disableIMUPower()
{
  pinMode(IMU_PWR_EN, OUTPUT); // Define the pinMode here in case a sleep function has disabled it
  digitalWrite(IMU_PWR_EN, LOW);
}
// Enable power for the IMU
void enableIMUPower()
{
  pinMode(IMU_PWR_EN, OUTPUT); // Define the pinMode here in case a sleep function has disabled it
  digitalWrite(IMU_PWR_EN, HIGH);
  pinMode(IMU_CS, OUTPUT);
  digitalWrite(IMU_CS, HIGH); // Pull CS high to disable the IMU
}

// Disable power for the GNSS active antenna
// Note: if this is called before assetTracker.begin, it will take 10 seconds to time out
void disableGNSSAntennaPower()
{
  // On v11 of the Asset Tracker, the antenna power is controlled by SARA GPIO2.
  // We need to pull GPIO2 (Pin 23) low to disable the power.
  assetTracker.setGpioMode(assetTracker.GPIO2, assetTracker.GPIO_OUTPUT, 0); // Disable
}
// Enable power for the GNSS active antenna
// Note: if this is called before assetTracker.begin, it will take 10 seconds to time out
void enableGNSSAntennaPower()
{
  // On v11 of the Asset Tracker, the antenna power is controlled by SARA GPIO2.
  // We need to pull GPIO2 (Pin 23) high to enable the power.
  assetTracker.setGpioMode(assetTracker.GPIO2, assetTracker.GPIO_OUTPUT, 1); // Enable
}

// Read VIN / 3
// Return the true voltage (compensating for processor type)
float readVIN()
{
  float vin = analogRead(VIN_DIV_3);
#if defined(ARDUINO_ARDUINO_NANO33BLE)
  // nRF52840 (Arduino NANO 33 BLE) is 3.3V and defaults to 10-bit
  // BUT the Schottky diode D2 on the 3.3V line reduces VDD to 3.05V
  vin *= 3.05 / 1023.0;
  vin *= 3.0; // Correct for resistor divider
#elif defined(ARDUINO_APOLLO3_SFE_ARTEMIS_MM_PB)
  vin *= 2.0 / 1023.0; // Artemis (APOLLO3) is 2.0V and defaults to 10-bit
  vin *= 2.5 / 1.5; // Artemis PB has a built-in 150k/100k divider
  vin *= 1.41; // Correction factor to compensate for the divider resistance
  vin *= 3.0; // Correct for resistor divider
#elif defined(ARDUINO_ARCH_ESP32)
  // ESP32 is 3.3V and defaults to 12-bit
  // Manual measurements:
  // VIN  ADC
  // 3.5V 1150
  // 4.0V 1350
  // 4.5V 1535
  // 5.0V 1735
  // 5.5V 1930
  // 6.0V 2130
  // so, VIN = (ADC / 392) + 0.565
  vin /= 392;
  vin += 0.565;
#elif defined(ARDUINO_ARCH_SAMD)
  // SAMD51 is 3.3V and defaults to 10-bit
  // BUT the Schottky diode D3 on the 3.3V line reduces VDD to 3.02V
  vin *= 3.02 / 1023.0;
  vin *= 3.0; // Correct for resistor divider
#elif defined(ARDUINO_ARCH_STM32)
  // STM32 is 3.3V and defaults to 10-bit
  vin *= 3.3 / 1023.0;
  vin *= 3.0; // Correct for resistor divider
#else
  vin *= 3.0; // Undefined PB!
#endif
  return (vin);
}
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

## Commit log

2020-09-14 Almost ready for airwire review
    [MicroMod_Asset_Tracker.brd, MicroMod_Asset_Tracker.sch]
2020-09-15 Ready for airwire review
    [MicroMod_Asset_Tracker.brd, MicroMod_Asset_Tracker.sch]
2020-09-18 Updates to support the ESP32 PB
    [MicroMod_Asset_Tracker.brd, MicroMod_Asset_Tracker.sch]
2020-09-21 Work in progress - 14 airwires left!
    [MicroMod_Asset_Tracker.brd, MicroMod_Asset_Tracker.sch]
2020-09-23 Ready for review
    [MicroMod_Asset_Tracker-Panel.GBL, MicroMod_Asset_Tracker-Panel.GBO, MicroMod_Asset_Tracker-Panel.GBP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]
2020-09-24 Replaced the Level Shifters
    [MicroMod_Asset_Tracker.brd, MicroMod_Asset_Tracker.sch]
2020-09-25 Rerun panelizer to get correct panel size.
    [MicroMod_Asset_Tracker-Panel.brd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]
2020-09-29 Added details for the 27pF and 33pF caps.
    [MicroMod_Asset_Tracker.brd, MicroMod_Asset_Tracker.sch]
2020-10-12 Added the missing PROD_IDs
    [MicroMod_Asset_Tracker.brd, MicroMod_Asset_Tracker.sch]
2020-10-13 Updated to use the revised SMD SMA connector footprint
    The footprint for the SMA now includes the toolpath for a 1mm end-mill
    [MicroMod_Asset_Tracker.brd, MicroMod_Asset_Tracker.sch]
2020-10-30 Adding some pin magic to let this run on all the PBs.
2020-11-02 Adding a draft of Example2 - a basic IMU test
2020-11-03 Updating Example2_IMU. Corrected SARA_PWR polarity.
    [AssetTrackerPins.h, AssetTrackerPins.ino, AssetTracker_Example2_IMU.ino]
2020-11-03 Added Example5 Qwiic (Power Switch)
2020-11-03 Adding Example7 GNSS Antenna Power
2020-11-03 Added Example8 External SPI (Micro OLED)
2020-11-04 Added Example10 IMU Wake_On-Motion
2020-11-06 Added SIM Status reporting with callback. Swapped examples 12 and 13.
    [AssetTrackerPins.h, AssetTrackerPins.ino, AssetTracker_Example11_GNSS_GPRMC.ino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]
2020-11-17 Adding the Packet Switched Data examples: Ping and HTTP GET/POST
2020-11-19 Updates for V11 of the PCB
    [MicroMod_Asset_Tracker.brd, MicroMod_Asset_Tracker.sch]
2020-11-23 Adding Example20 - Test UART Pins. Uses custom commands to test the IO pins.
2020-11-23 Adding Example21 - Test I2C Pins
2020-11-23 Adding Example22 - bidirectional test of the SARA EXT_INT pin
2020-11-25 Updated files for v11 after production review
    [MicroMod_Asset_Tracker.brd, MicroMod_Asset_Tracker.sch]
2020-11-26 Adding production files for v11
    [MicroMod_Asset_Tracker-Panel.brd, MicroMod_Asset_Tracker.brd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]
2020-12-03 Create MicroMod_Asset_Tracker.zip
    Zip folder of the schematic/board files to upload to Sparkle
2020-12-05 Adding the PROD_ID for the SARA-R510M8S
    [MicroMod_Asset_Tracker.brd, MicroMod_Asset_Tracker.sch]
2021-02-04 Revert "Updating Examples 1-5 after testing on V11 hardware"
    This reverts commit 6160b7a9624f28f4c2bda135ea040022309603c5.
    [AssetTrackerPins.h, AssetTrackerPins.ino, AssetTracker_Example1_Blink.ino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]
2021-10-06 Add STM32
2021-10-28 Change BATTVIN3 to 2 so code reads "A2" (PA_1) correctly
    [AssetTrackerPins.h]
2021-12-28 Corrections for v2 of Apollo3 (Artemis)
    [AssetTrackerPins.h, AssetTrackerPins.ino]
2022-01-15 Add examples 25-27:
    25: u-blox AssistNow Online - GET and push AssistNow aiding information to an external u-blox GNSS
    26: u-blox AssistNow Offline - GET and push AssistNow aiding information to an external u-blox GNSS
    27: GNSS NTRIP Caster - open a socket to an NTRIP Caster, receive RTCM data and push it to an external GNSS, receive GPGGA NMEA from the GNSS and push to the Caster, all done with callbacks where pos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
2022-01-17 Switch to setSocketReadCallbackPlus - for binary compatibility
2022-01-17 Improve printing on Artemis
2022-01-17 Store the AssistNow file contents and NTRIP credentials in allocated memory - to help reduce stack problems on Mbed OS (Artemis & nRF52840)
    [AssetTrackerPins.ino, AssetTracker_Example25_AssistNowOnline.ino, AssetTracker_Example26_AssistNowOffline.ino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]

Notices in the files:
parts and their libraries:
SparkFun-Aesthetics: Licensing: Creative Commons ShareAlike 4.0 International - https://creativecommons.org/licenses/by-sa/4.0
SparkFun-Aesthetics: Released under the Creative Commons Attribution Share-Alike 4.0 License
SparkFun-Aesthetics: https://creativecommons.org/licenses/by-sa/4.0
